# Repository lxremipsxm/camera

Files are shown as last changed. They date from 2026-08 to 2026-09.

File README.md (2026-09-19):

# Camera

## Information
1. [Component List and Hardware Notes](HardwareNotes.md)
2. [Schematic Details and Images](camCAD/README.md)

## Use (In Progress)
There are four buttons meant for a user interface

## Personal Note
This is the continuation of my stmcam project that I had been working on for a long time, in [this repository](https://github.com/lxremipsxm/stmcam) if you are interested. The goal of that project was to have a completely naked approach to building this camera, using raw C, no Hardware Abstraction Layer and minimal library usage. It was a very code-centered project, and reasonably so, as I had no electrical knowledge or knowledge of using CAD to build (or at least prototype) PCBs. At the time, I was fully confident I could make this with a perfboard and some solder at home if I had the right components, which I did eventually purchase from Digikey. However, I had selected a board without Parallel Capture/DCMI and tried to work my way around it until the workload became utterly infeasible and would have led to me making a project of subpar quality even if I succeeded. It was incredibly frustrating, but I still haven't given up on this project. This repository is a fresh start, and I am changing my approach. I have a new board planned, I have the incredible resource of KiCAD 10.0, and I have developed the skills to build my own PCBs and print them. Additionally, this time I will not dive headfirst into baremetal programming as much. I will use HAL to make a functional project, and I do eventually have to create my own interface to facilitate the use of a OV7670 library I have found on GitHub, which means I still get to code a solid amount without leaving all of it to HAL. In addition to this, because of the need for fast decision making and tight timing constraints, I will use an RTOS implementation for a multithreaded application.

So here is my camera. I am so much more confident in this project's success.

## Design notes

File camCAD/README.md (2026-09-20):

## Component Connections and Layout

### Schematics

#### STM32 Power Requirements Schematic (power_conns.kicad_sch)
This schematic is based off of the power requirements detailed in the [STM32 F405xx/F407xx datasheet](https://www.st.com/content/ccc/resource/technical/document/datasheet/ef/92/76/6d/bb/c2/4f/f7/DM00037051.pdf/files/DM00037051.pdf/jcr:content/translations/en.DM000370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) and cross-checked with the [ST Application Note AN4488](https://www.alldatasheet.com/datasheet-pdf/view/701384/STMICROELECTRONICS/AN4488.html) for good measure.

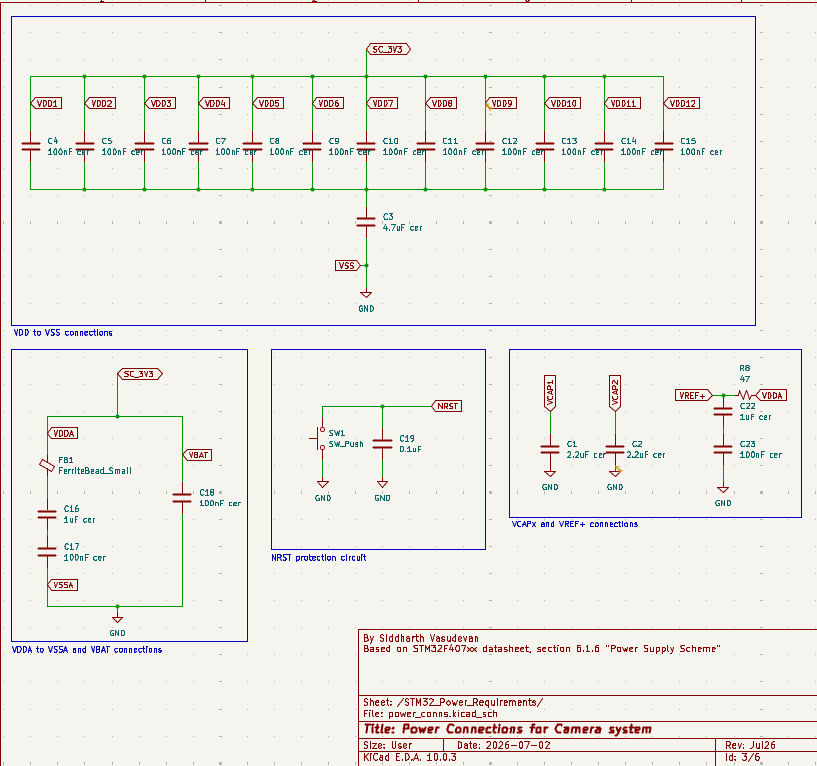
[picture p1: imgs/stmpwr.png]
Power Connections Schematic


#### Power Supply and Charging Schematic (buck.kicad_sch)
This schematic contains all of the circuitry necessary to make charging possible and exposes pins to the battery. It includes connections for a USB-C socket that serves as the charging port for the camera, connections for the Dynamic Power Path Management IC (charging + power management), the buck converter circuitry to efficiently step down the battery's 3.7V to 3.3V, and the battery terminals, which will use an XH socket. (Initially I planned to have the buck converter on a separate schematic, hence the filename, but there wasn't enough detail to justify a separate schematic)

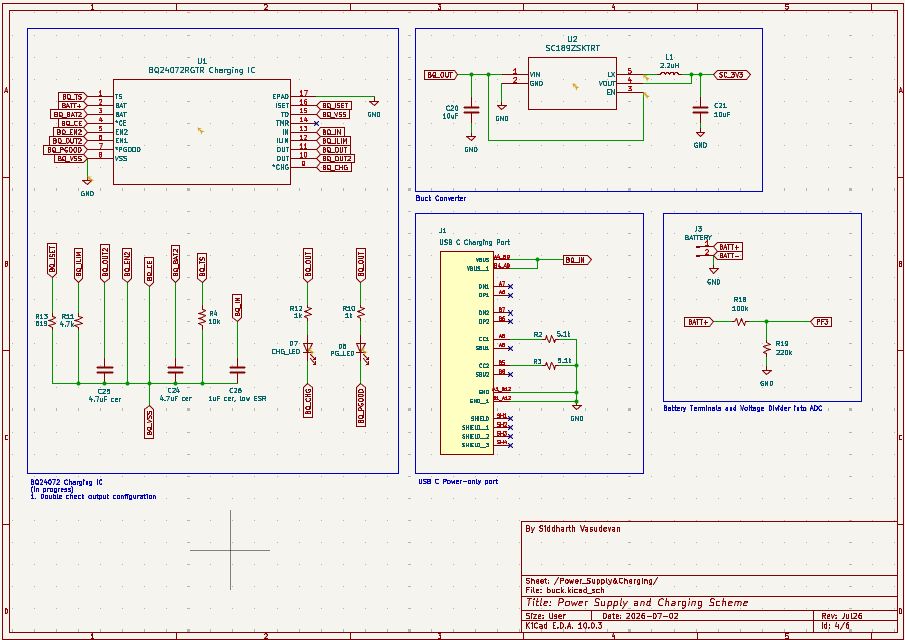
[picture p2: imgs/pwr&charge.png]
Power Supply and Charging Schematic


#### Components Schematic (components.kicad_sch)
This schematic contains the component connections that provide all the functionality of a camera. It contains the OV7670 Camera Module, the ILI9341 Display header, activity LEDs, and the MicroSD transflash breakout board.

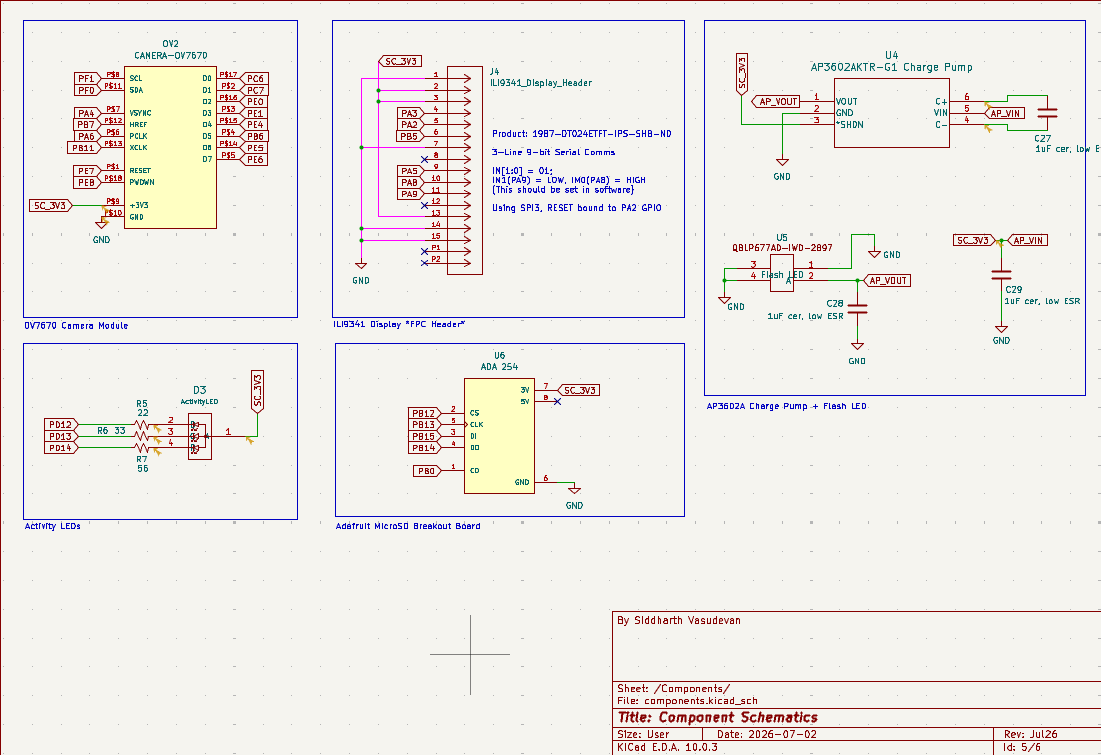
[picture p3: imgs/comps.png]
Components Schematic


#### STM32F407 schematic (f407zgt6.kicad_sch)
Contains the STM32F407ZGT6 LPQF144 chip. ~~In the near future I will put more circuits in this schematic, such as the bootloader switch.~~
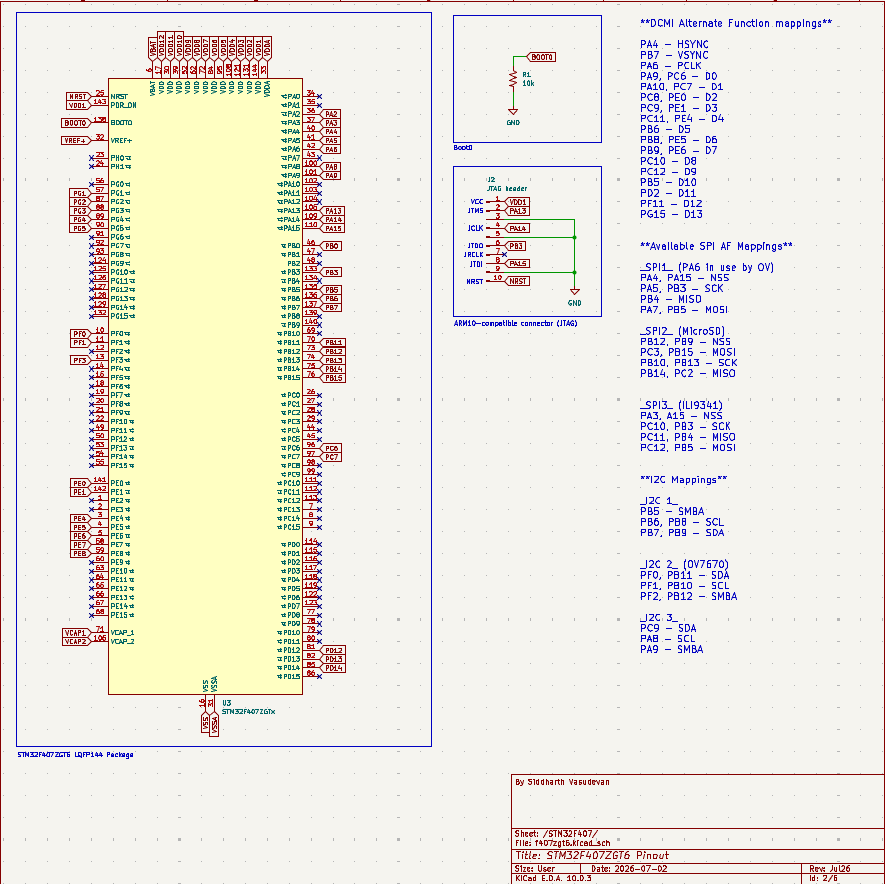
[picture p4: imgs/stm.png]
STM32 Schematic


#### User Interface (user_interface.kicad_sch)
This schematic contains the buttons that will aid the user in communicating with the camera, such as taking pictures, toggling flash, deleting pictures, and navigating saved pictures via a picture menu.

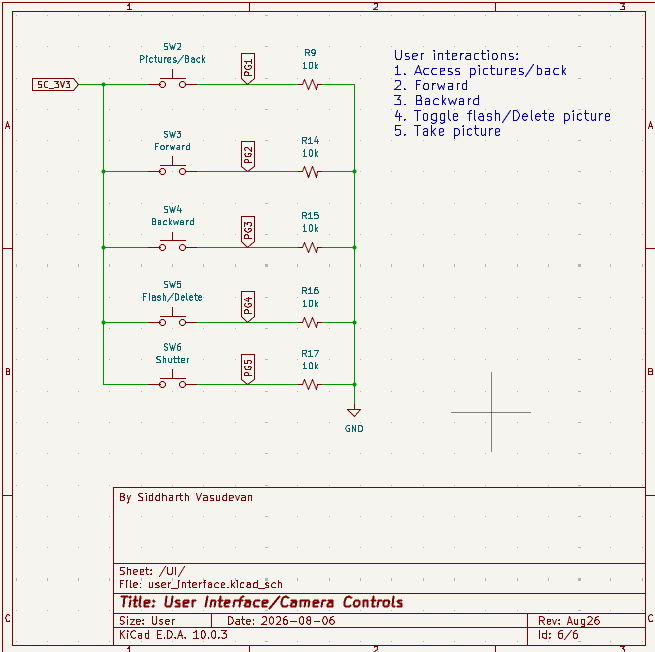
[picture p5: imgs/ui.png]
User Interface Schematic


### PCB Layout (Two Layer)
I was recommended to use four layers to separate the ground and VCC Planes better, but this is what I got routing with a two-layer PCB, with the back CU layer housing a ground fill zone. 
The following layout was verified by the DRC. All dimensions are in mm.
| Layout | 3D Model |
| --- | --- |
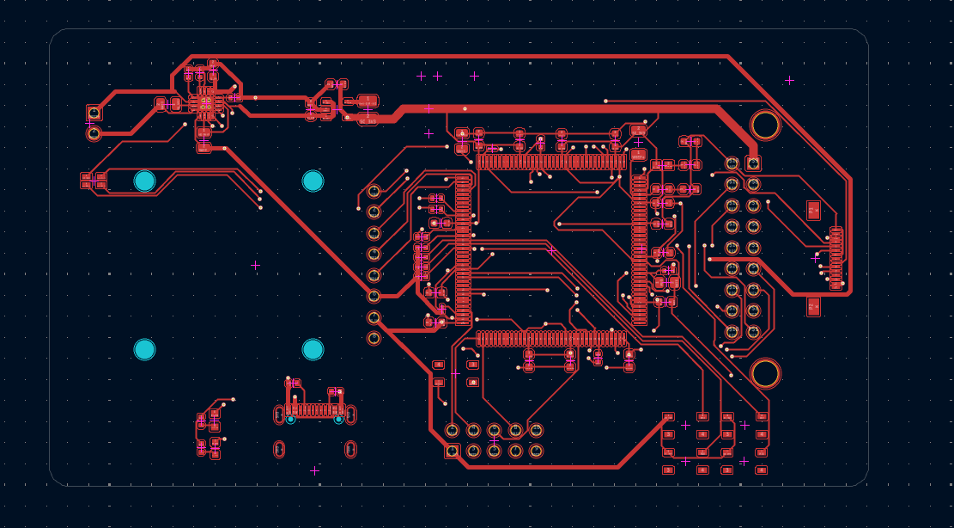
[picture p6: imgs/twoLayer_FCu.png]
Front Layout CU only
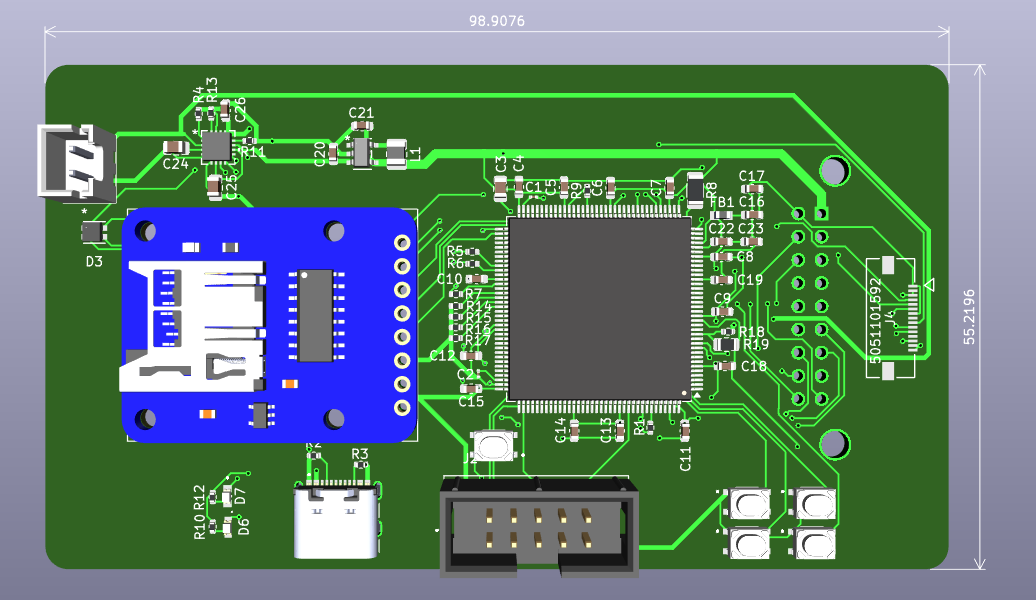
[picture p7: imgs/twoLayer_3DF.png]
Front 3D Model
|  |  |

| Back Layout | 3D Model |
| --- | --- |
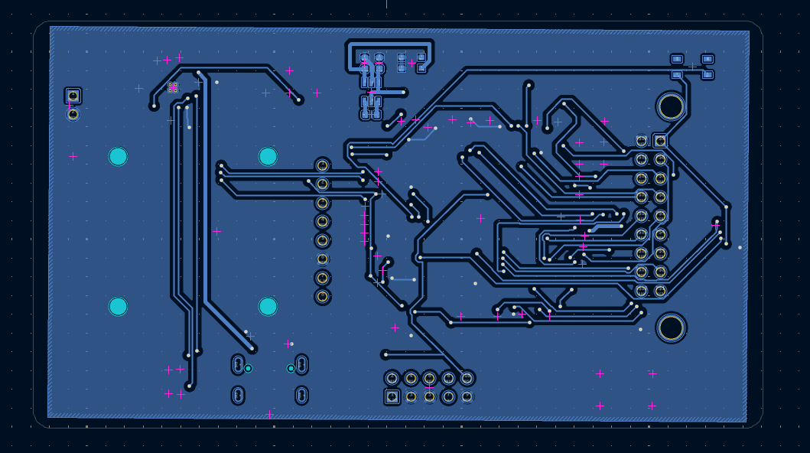
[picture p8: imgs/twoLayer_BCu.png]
Back Layout Cu
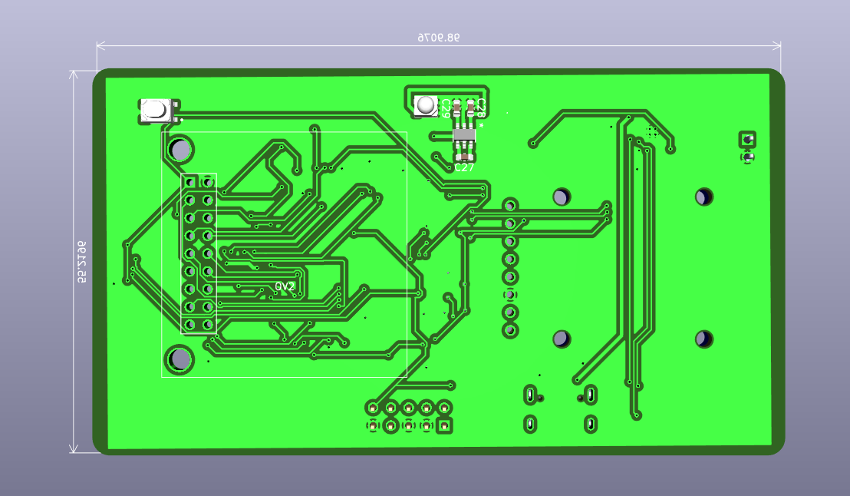
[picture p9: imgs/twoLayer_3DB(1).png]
Back 3D Model
|  |  |

### PCB Layout (Four Layer)
This PCB will be printed once I reverify the schematics and layout. I was able to make the board a little more compact with four layers.
The layout was verified by the DRC. All dimensions are in mm.

| Front CU | Back CU |
|--- | --- |
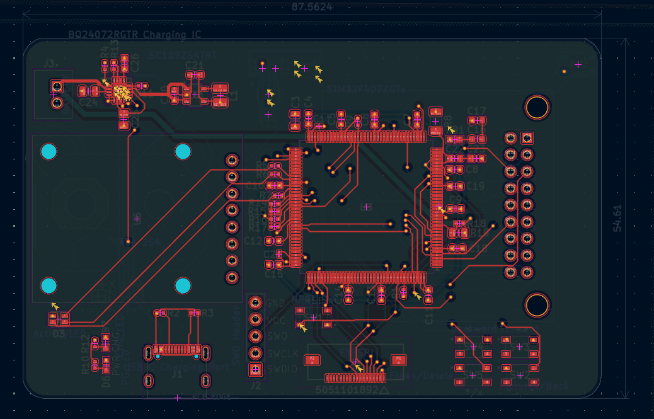
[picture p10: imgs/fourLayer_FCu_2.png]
Front Layout CU
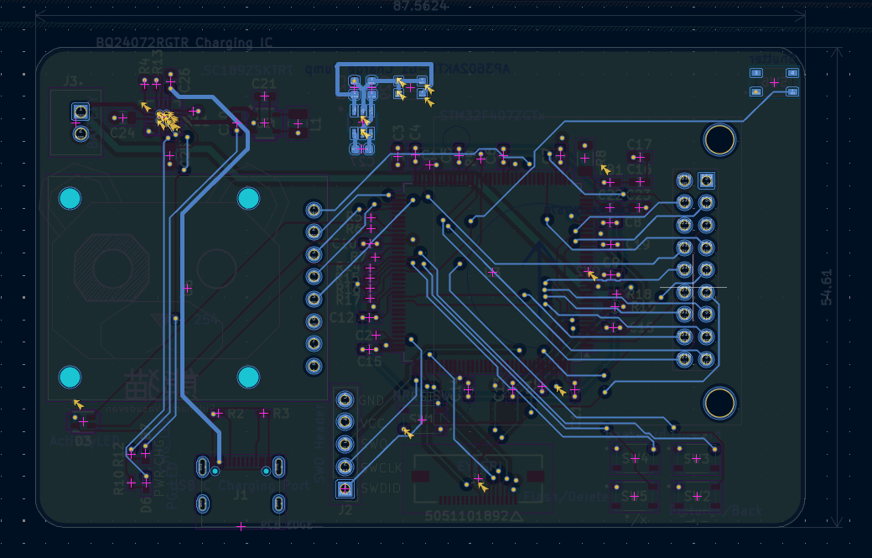
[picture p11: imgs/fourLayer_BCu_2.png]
Back Layout CU only
|  |  |
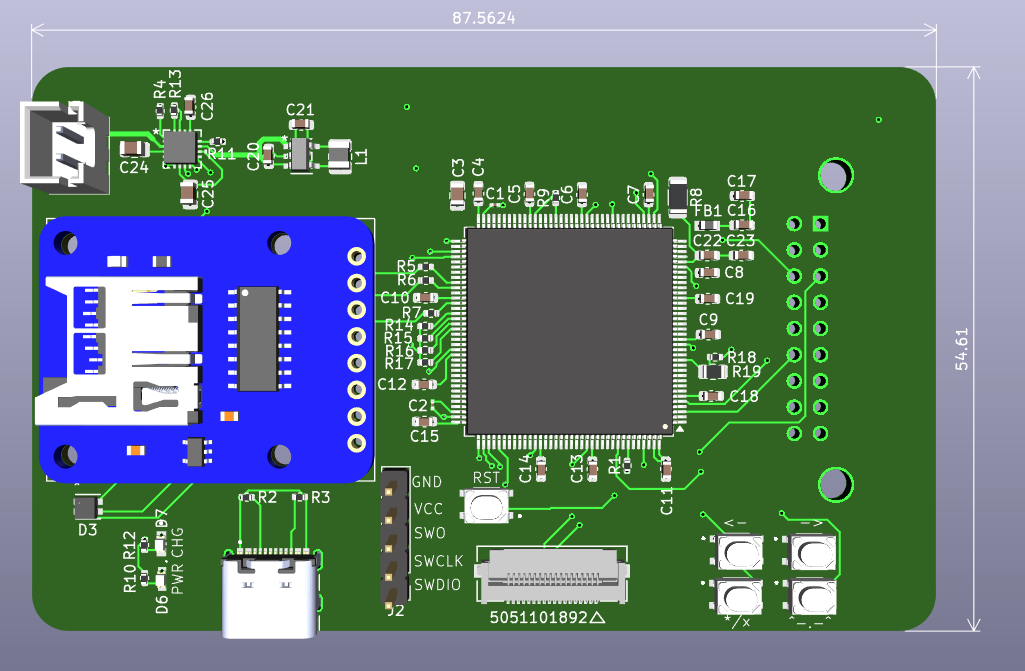
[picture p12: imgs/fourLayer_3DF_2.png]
Front 3D
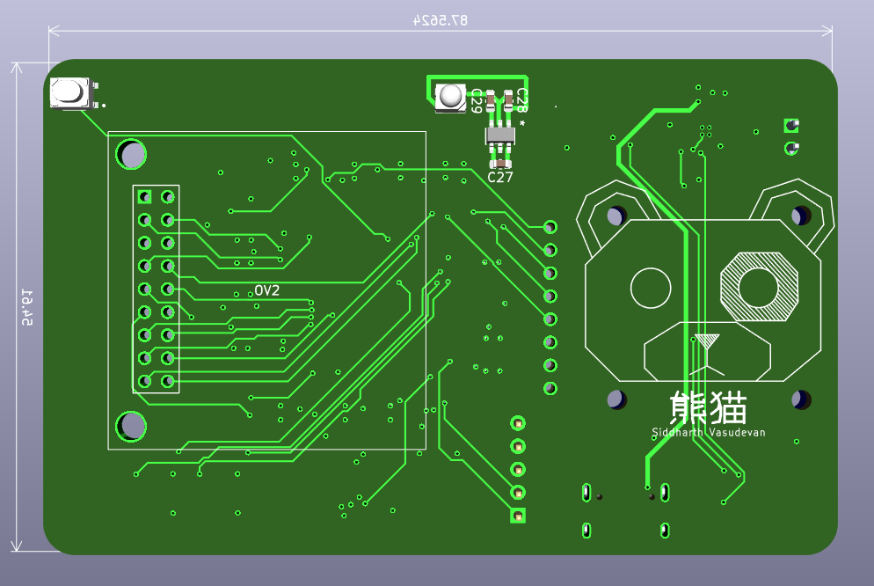
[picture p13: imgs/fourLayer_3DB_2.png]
Back 3D
|  |  |

| VCC CU | GND CU |
| --- | --- |
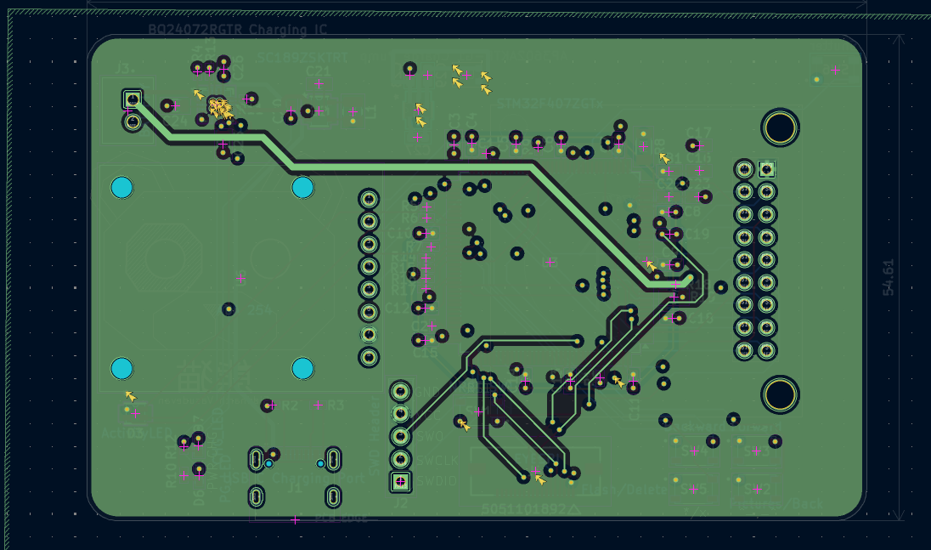
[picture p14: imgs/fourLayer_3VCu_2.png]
VCC Layout CU
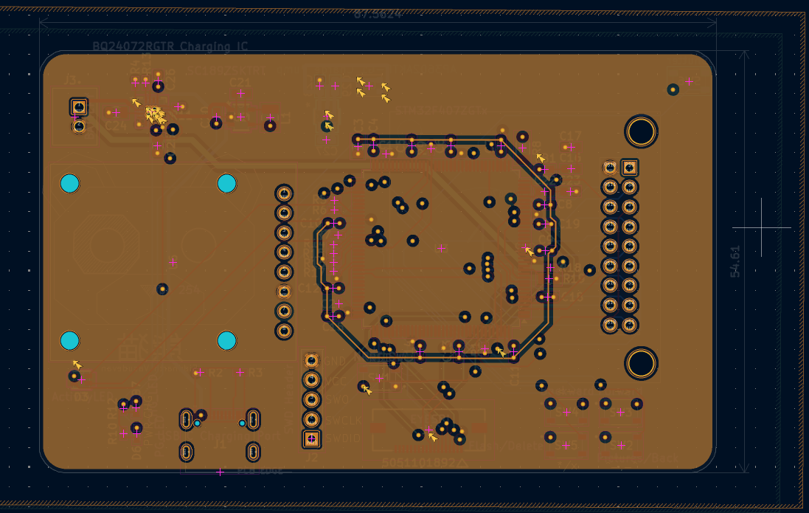
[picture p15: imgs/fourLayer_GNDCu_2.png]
GND Layout CU
|  |  |

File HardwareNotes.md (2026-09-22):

# Notes about Hardware

---

## Major Component List (Digikey Part Numbers Included)
1. STM32F407: 497-11766-ND
2. OV7670: 1188-CAMERA-OV7670-ND
3. Adafruit MicroSD Breakout: 1528-1462-ND
~~ 4. ILI9341: 1987-DT024ETFT-IPS-SHB-ND~~ 
4. Display Module (ADA 4311): 1528-4311-ND
5. RGB LED: CLMVC-FKA-CL1D1L71BB7C3C3CT-ND
6. Charge-Pump: 31-AP3602AKTR-G1CT-ND
7. Flash LED: 1516-QBLP677AD-IWD-2897CT-ND
8. Buck Converter: SC189ZSKCT-ND
9. Battery: 1471-MIKROE-4474-ND
10. Charging IC: 296-38871-1-ND
11. USB-C for Charging: 2223-UJ20-C-H-G-SMT-1-P16-TRCT-ND
12. PGOOD Indicator LED (Green): 160-LTST-C190GKTCT-ND 
13. CHG Indicator LED (Red): 160-1436-1-ND 

## Resistors, Capacitors, Inductors, and Headers
### Miscellaneous
1. SWD ARM-10 compatible header: S9169-ND
2. FPC Socket: WM12374CT-ND
3. Battery Connector: 455-B2B-XH-A-ND
4. Push Button (NRST): 4809-SKRPABE010CT-ND
5. VDDA Ferrite Bead: 490-14396-1-ND
6. Buck Converter 2.2uH Inductor (rated at least 1.5 A for system load): 587-3226-1-ND  

### Capacitors
7. 100nF (0.1uF) ceramic decoupling (STM32 power): 1276-CL10E104KC8VPNCCT-ND 
8. 1uF low ESR ceramic decoupling (charge pump): 587-6336-1-ND
9. 1uF ceramic decoupling (STM32 power): 587-6336-1-ND
10. 10uF ceramic decoupling (buck converter): 490-12538-1-ND
11. 0.1uF NRST power switch capacitor: 1276-CL10E104KC8VPNCCT-ND 
12. 4.7uF DPPM ceramic decoupling: 1276-1065-1-ND
13. STM32 VCAP 2.2uF ceramic decoupling: 478-KGM03CR50J225MHCT-ND

### Resistors
14. 619 DPPM ISET: P619LCT-ND
15. 4.7k DPPM ILIM: 311-4.7KLRCT-ND
16. 1k Indicator LED: 311-1.00KLRCT-ND 
17. 5.1k USB C Socket: P5.10KLCT-ND
18. 10k BQ_TS & BOOT0: RMCF0402FT10K0CT-ND  
19. 22 RGB_B LED: 541-22.0LCT-ND
20. 33 RGB_G LED: 541-33.0LCT-ND
21. 56 RGB_R LED: A129612CT-ND
22. 47 VDDA-VREF: P47BCCT-ND
23. 100k Voltage Divider R into ADC junction: 311-100KLRCT-ND 
24. 220k Voltage Divider R from ADC to GND: A126350CT-ND 

## STM32F407 + Recommendations from manufacturer
1. PCB should be a multilayer one with separate layers for VSS and VDD
2. Don't have one singular GND return plane, try and ground components individually
3. Recommended to put buck converter far from other components to avoid noise 
4. Unused counters or I/O should not be left free, either set to 1/0 or peripheral disabled.
5. Draws <= 150mA

## OV7670
1. Draws ~18 mA, maximum not provided by documentation, USE 25-50mA just in case

## MicroSD
1. Draws ~100mA worst case scenario

## SWD Header ~~JTAG header~~
1. Exposes the JTAG peripheral that can be used to debug with an STLink

## ILI9341

### Header
1. 

### Actual device
1. Backlight draws <= 60mA
2. Functional part draws <= 15mA

## AP3602A Regulated Charge-Pump
1. Outputs up to 250mA current after charging
2. SHDN cannot be floating, tie to GPIO pin HIGH (enable) or LOW, never leave floating
3. Bypass VOUT with a 1uF to 22uF low ESR *ceramic* cap to GND
4. Bypass VIN with another 1uf-22uF low ESR ceramic cap to GND
5. Flying capacitor is separate from these two capacitors
6. Draws ~75mA while firing flash

## Flash LED
1. Current draw see Charge Pump^
2. V_LED = 3.2V
3. V_Out (Charge-Pump) = 5V
4. Required LED Current ~= 50mA
5. R (resistor) >= V/I <= (5-3.2V)/(50*10^-3) >= 36 Ohms

## SC189Z 3.6V->3.3V Buck Converter
1. EN pin should be tied to VIN on itself
2. LX is a switching node, connect inductor between here and output cap
3. Place components as closely as possible to the SC189Z.
4. For SOT-23 package at Vin = 4.0V, Vout = 3.3V and I_load ~= 560 mA, efficiency is roughly 93%

## Power + Activity RGBLED
1. Common Anode (3.3V)
2. PWM-controlled, using Advanced timer TIM4
3. B CH1, G CH2, R CH3
4. Draws ~(25 + 13 + 13) mA = ~51 mA

### Resistor and control details
V_GPIO <= 3.3V

#### Red
V_red = 1.9 V
I_avg = 25*10^-3 A

R_red >= (3.3-1.9)/(2.5*10^-3) = 53.85 Ohm ~= 56 Ohm

#### Green
V_green = 2.9 V
I_avg = 13*10^-3 A

R_green = (3.3-2.9)/(13*10^-3) >= 30.77 Ohm ~= 33 Ohm

#### Blue
V_blue = 3.0 V
I_avg = 13*10^-3 A

R_blue = (3.3-3.0)/(13*10^-3) >= 23.08 Ohm ~= 22 Ohm

# Power Considerations for Battery

## Current Needs of Components
1. STM32 = 150mA
2. OV7670 = 50 mA
3. MicroSD Breakout = 100mA
4. ILI9341 = 75mA
5. Charge-pump + Flash = 75mA
6. LEDs ~= 51 + 3(20) = 111mA

Total = 150 + 50 + 100 + 75 + 75 + 111 = 350 + 75 + 111 = 561 mA

## Safety Margin and Buck Converter Efficiency
~~Once I choose a buck converter, I will include the efficiency of that to decide the battery configuration.~~
With the selected buck converter, the SC189Z, and a 4.0V input with 3.3V output configuration, the efficiency is ~93%.

Using this and a safety margin of 20% to account for battery aging:
Estimated needs (safety margin of 20%, 4 hour usage) = (561 * 4)/0.93 * 1.2 = 2895.5 mAh, which we can round up to 3000mAh.

Battery selected (Items 10 and 11 in **Component List**).

# Charging method

## MLP805660 Battery pack
1. 3.7V, 3000mAh
2. Discharges 0.2 C-rate
3. Standard charging 0.5C (C-rate, NOT coulombs like I initially thought), takes about 5.5-6.5 hours to charge fully 
4. Current needed for standard charging, therefore, is 0.5C * 3000mAh = 1.5A

## BQ24072 Charging IC
1. ILIM doesn't need to be programmed in EN2=LO EN1=HI mode (USB 500mA), so I've selected a 4.7k Ohm resistor to GND
2. $797 <= $K_{ISET}$ <= 975$. I use this to calculate the resistor needed to program the ISET pin.
3. $I_{CHG}$ can be 1.5A, which I will keep. $R_{ISET} = K_{ISET}/I_{CHG}$
4. $531.3 \le R_{ISET} \le 650$. The valid range is $590 \ge r \ge 8.9k$. I will use $R_{ISET} = 619$  

## USB C Socket
1. 

# Schematic/Layout Verification and Code Information

## ADA 4311 Display
(Verified 9/20)
| Header Pin # | 4311 Pin Name | STM Pin # | STM GPIO AF |
| ----- | ----- | ----- | ----- |
| 4 | SCK | PC10 | SPI3_SCK |
| 5 | MOSI | PC12 | SPI3_MOSI |
| 6 | MISO | PC11 | SPI3_MISO |
| 7 | DC (Data/CMD) | PC13 | NA |
| 8 | RESET | PC14 | NA |
| 9 | TFTCS | PA15 | SPI3_NSS |

## OV7670 Camera Module 
(Verified 9/20)

| OV Pin Name | STM Pin # | STM GPIO AF |
| --- | --- | --- |
| SCL | PF1 | I2C2_SCL | 
| SDA | PF0 | I2C2_SDA |
| VSYNC | PB7 | DCMI_VSYNC |
| HREF | PA4 | DCMI_HSYNC |
| PCLK | PA6 | DCMI_PIXCLK |
| XCLK | PB11 | TIM2_CH4 |
| RESET | PE7 | NA | 
| PWDWN | PE8 | NA |
| D0 | PC6 | DCMI_D0 |
| D1 | PC7 | DCMI_D1 |
| D2 | PE0 | DCMI_D2 |
| D3 | PE1 | DCMI_D3 |
| D4 | PE4 | DCMI_D4 |
| D5 | PB6 | DCMI_D5 |
| D6 | PE5 | DCMI_D6 |
| D7 | PE6 | DCMI_D7 |

## ADA 254 MicroSD Breakout
(Verified 9/20)

| 254 Pin Name | STM Pin # | STM GPIO AF |
| --- | --- | --- |
| CS | PB12 | SPI2_NSS |
| CLK | PB13 | SPI2_SCK |
| DI | PB15 | SPI2_MOSI |
| DO | PB14 | SPI2_MISO |
| CD (card detect) | PB0 | NA |

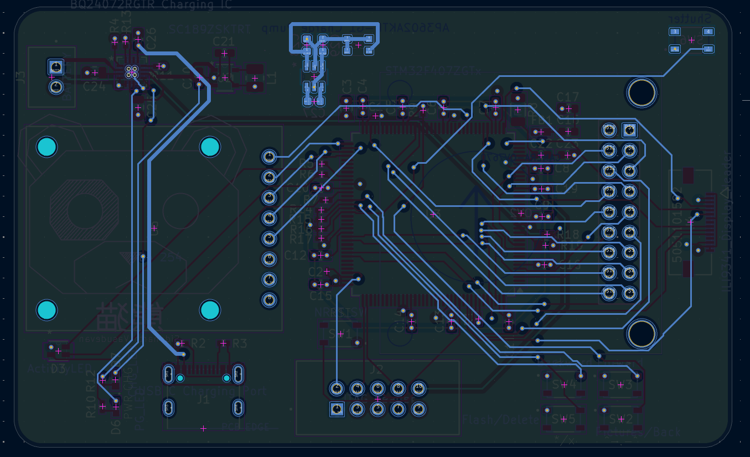
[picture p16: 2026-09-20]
imgs/fourLayer_BCu_1.png

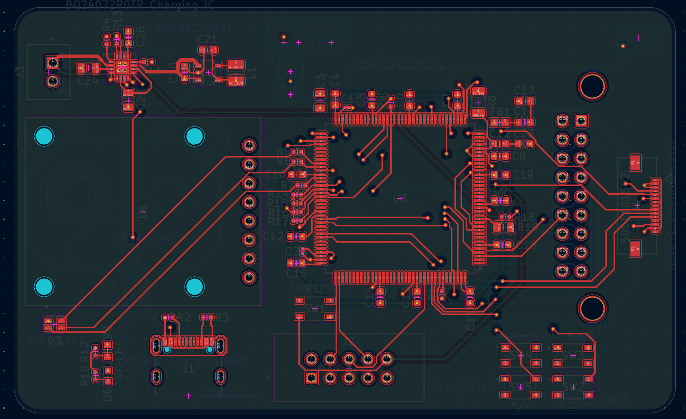
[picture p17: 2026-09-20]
imgs/fourLayer_FCu_1.png

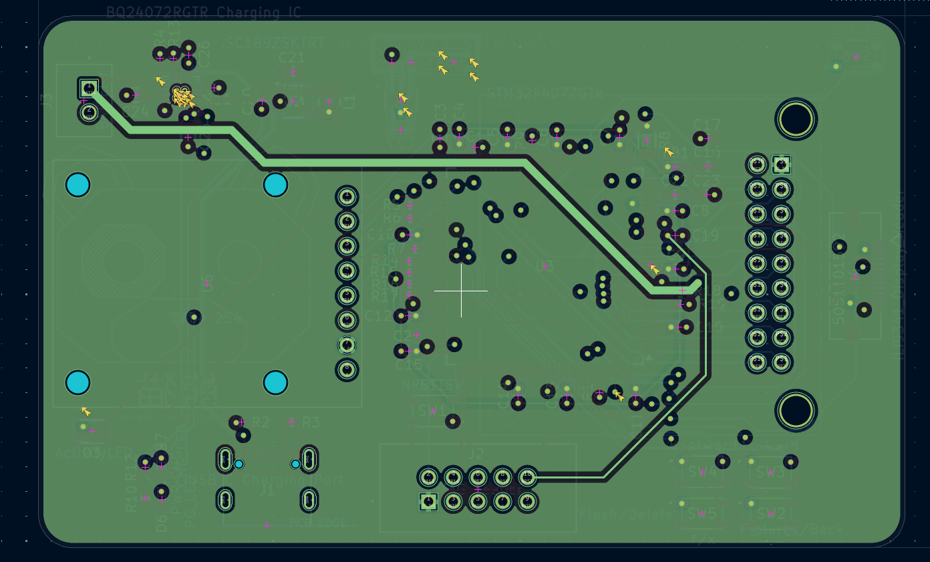
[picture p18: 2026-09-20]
imgs/fourLayer_3VCu_1.png

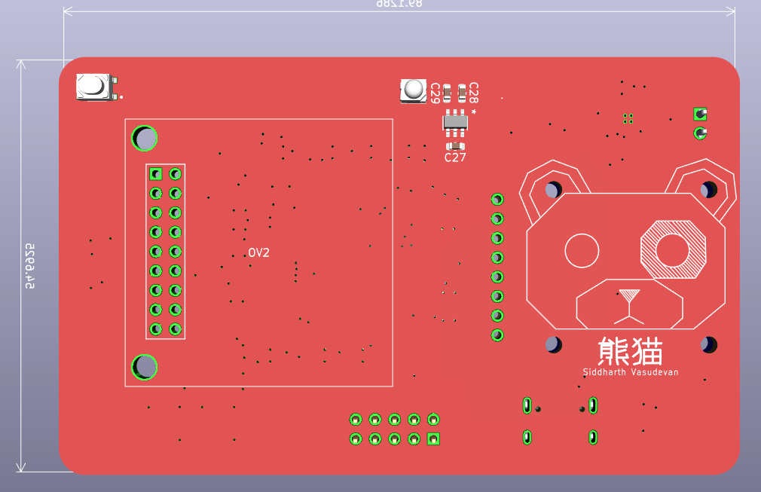
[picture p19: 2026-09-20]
imgs/fourLayer_3DB_1.png

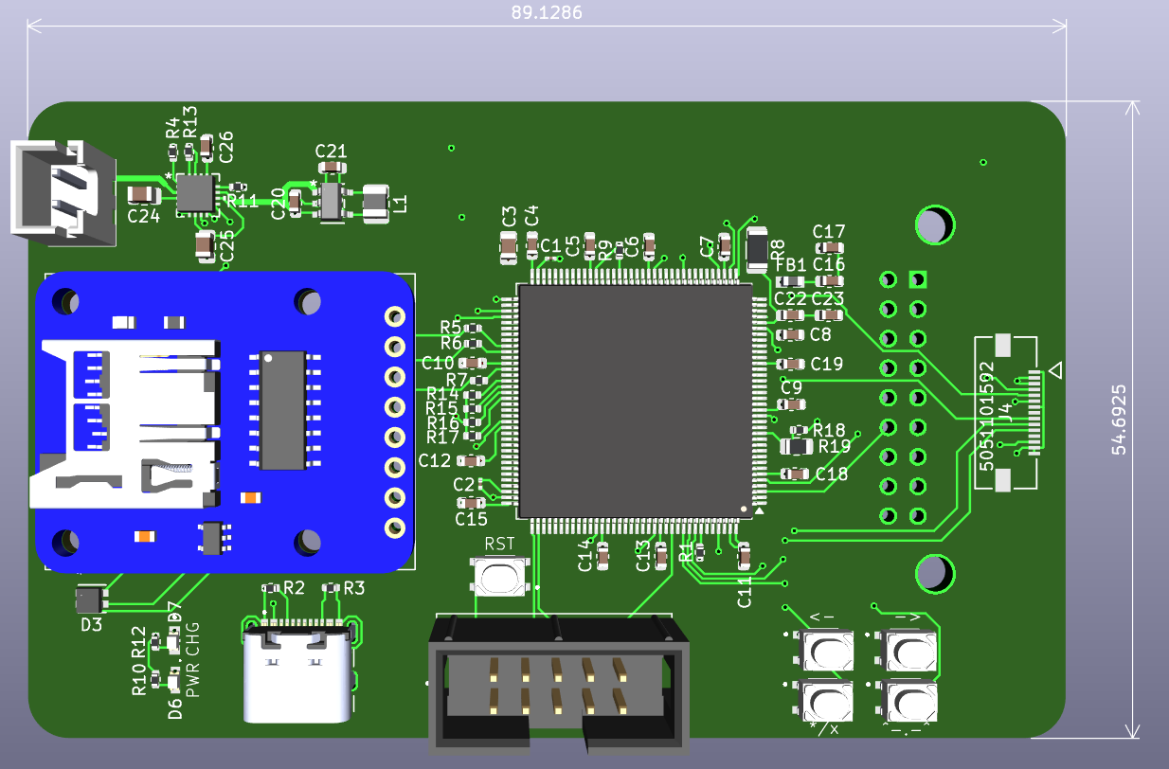
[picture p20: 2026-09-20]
imgs/fourLayer_3DF_1.png

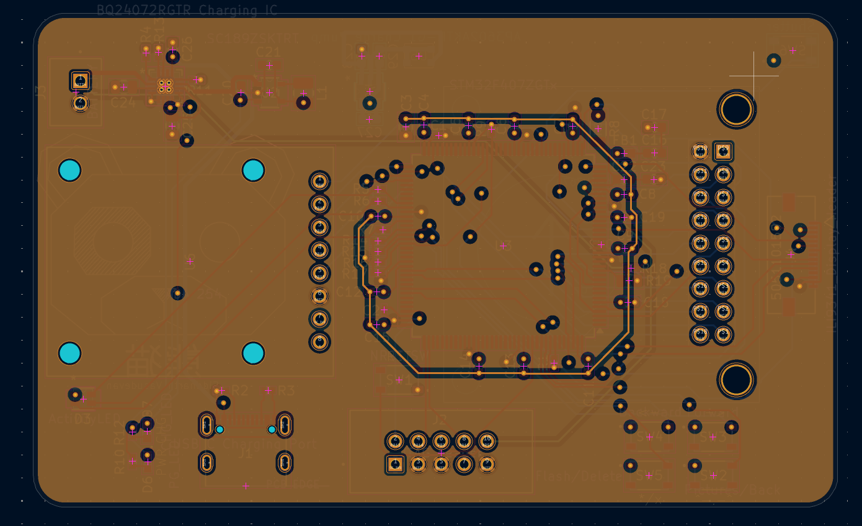
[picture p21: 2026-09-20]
imgs/fourLayer_GNDCu_1.png

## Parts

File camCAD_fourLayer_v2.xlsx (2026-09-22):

Reference | Value | Digikey Part No | Qty | Buy Qty | Total Price | Footprint | Datasheet
R8 | 47 | P47BCCT-ND | 1 | 4 | ! | Resistor_SMD:R_1206_3216Metric
R19 | 220k | A126350CT-ND | 1 | 10 | $0.42 | Resistor_SMD:R_0805_2012Metric
R18 | 100k | 311-100KLRCT-ND | 1 | 10 | $0.42 | Resistor_SMD:R_0402_1005Metric
R13 | 619 | P619LCT-ND | 1 | 10 | $0.31 | Resistor_SMD:R_0402_1005Metric
R11 | 4.7k | 311-4.7KJRCT-ND | 1 | 10 | $0.20 | Resistor_SMD:R_0402_1005Metric
R10,R12 | 1k | 311-1.00KLRCT-ND | 2 | 10 | $0.21 | Resistor_SMD:R_0402_1005Metric
R7 | 56 | A129612CT-ND | 1 | 10 | $0.30 | Resistor_SMD:R_0402_1005Metric
R6 | 33 | 541-33.0LCT-ND | 1 | 10 | $0.32 | Resistor_SMD:R_0402_1005Metric
R5 | 22 | 541-22.0LCT-ND | 1 | 4 |  | Resistor_SMD:R_0402_1005Metric
R2,R3 | 5.1k | P5.10KLCT-ND | 2 | 5 |  | Resistor_SMD:R_0402_1005Metric
R1,R4,R9,R14,R15,R16,R17 | 10k | RMCF0402FT10K0CT-ND | 7 | 10 |  | Resistor_SMD:R_0402_1005Metric
U3 | STM32F407ZGTx | 497-11766-ND | 1 | 1 |  | Package_QFP:LQFP-144_20x20mm_P0.5mm | https://www.st.com/resource/en/datasheet/stm32f407zg.pdf
L1 | 2.2uH | 587-3226-1-ND | 1 | 4 |  | Inductor_SMD:L_1008_2520Metric
J2 | SWD Header |  | 1 | 0 |  | Connector_PinHeader_2.54mm:PinHeader_1x05_P2.54mm_Vertical
J4 | EYESPI | WM12374CT-ND | 1 | 3 |  | CON_5051101892_MOL | https://www.molex.com/en-us/products/part-detail-pdf/5051101892?display=pdf
C3,C24,C25 | 4.7uF cer | 1276-1065-1-ND | 3 | 3 |  | Capacitor_SMD:C_0805_2012Metric
C26,C27,C28,C29 | 1uF cer, low ESR | 587-6336-1-ND | 4 | 0 |  | Capacitor_SMD:C_0603_1608Metric
C20,C21 | 10uF |  | 2 | 0 |  | Capacitor_SMD:C_0603_1608Metric
C19 | 0.1uF |  | 1 | 0 |  | Capacitor_SMD:C_0603_1608Metric
C16,C22 | 1uF cer |  | 2 | 0 |  | Capacitor_SMD:C_0603_1608Metric
C4,C5,C6,C7,C8,C9,C10,C11,C12,C13,C14,C15,C17,C18,C23 | 100nF cer |  | 15 | 0 |  | Capacitor_SMD:C_0603_1608Metric
C1,C2 | 2.2uF cer | 478-KGM03CR50J225MHCT-ND | 2 | 5 |  | Capacitor_SMD:C_0201_0603Metric
SW6 | Shutter | 4809-SKRPABE010CT-ND | 1 | 1 |  | 1_Switches:SW_SKRPABE010
SW5 | Flash/Delete | 4809-SKRPABE010CT-ND | 1 | 1 |  | 1_Switches:SW_SKRPABE010
SW4 | Backward | 4809-SKRPABE010CT-ND | 1 | 1 |  | 1_Switches:SW_SKRPABE010
SW3 | Forward | 4809-SKRPABE010CT-ND | 1 | 1 |  | 1_Switches:SW_SKRPABE010
SW2 | Pictures/Back | 4809-SKRPABE010CT-ND | 1 | 1 |  | 1_Switches:SW_SKRPABE010
SW1 | NRST_SW | 4809-SKRPABE010CT-ND | 1 | 3 |  | 1_Switches:SW_SKRPABE010
J1 | USB C Charging Port | 2223-UJ20-C-H-G-SMT-1-P16-TRCT-ND | 1 | 2 |  | 1_Sockets:SAMESKY_UJ20-C-H-G-SMT-1-P16-TR
U6 | ADA 254 | 1528-1462-ND | 1 | 2 |  | 1_MicroSD:MODULE_254
U5 | Flash LED | 1516-QBLP677AD-IWD-2897CT-ND | 1 | 2 |  | 1_LEDs:QBLP677AD-IWD-2897
D6 | PG_LED | 160-LTST-C190GKTCT-ND | 1 | 2 |  | 1_LEDs:LEDM1608X80_G
D7 | CHG_LED | 160-1436-1-ND | 1 | 2 |  | 1_LEDs:LEDC1608X35N_R
D3 | ActivityLED | CLMVC-FKA-CL1D1L71BB7C3C3CT-ND | 1 | 2 |  | 1_LEDs:CLMVC-FKA-CL1D1L71BB7C3C3_CRE | CLMVC-FKA-CL1D1L71BB7C3C3
J3 | BATTERY | 455-B2B-XH-A-ND | 1 | 2 |  | 1_Headers:JST_B2B-XH-A
FB1 | FerriteBead_Small | 490-14396-1-ND | 1 | 3 |  | 1_FerriteBeads:BEADC1608X95N
U1 | BQ24072RGTR Charging IC | 296-38871-1-ND | 1 | 2 |  | 1_DPPMs:RGT16_1P7X1P7 | https://www.ti.com/lit/gpn/bq24072
U4 | AP3602AKTR-G1 Charge Pump | 31-AP3602AKTR-G1CT-ND | 1 | 2 |  | 1_ChargePump:SOT-23-6_DIO | AP3602AKTR-G1
OV2 | CAMERA-OV7670 |  | 1 | 0 |  | 1_Cameras:CAMERA-OV7670-DIP
U2 | SC189ZSKTRT | SC189ZSKCT-ND | 1 | 2 |  | 1_BuckConverters:SOT23-5-SC189_SEM | SC189ZSKTRT
 | ADA4311 | 1528-4311-ND | 1 | 1
 | Battery | 1471-MIKROE-4474-ND | 1 | 1
 |  |  |  |  | $2.18

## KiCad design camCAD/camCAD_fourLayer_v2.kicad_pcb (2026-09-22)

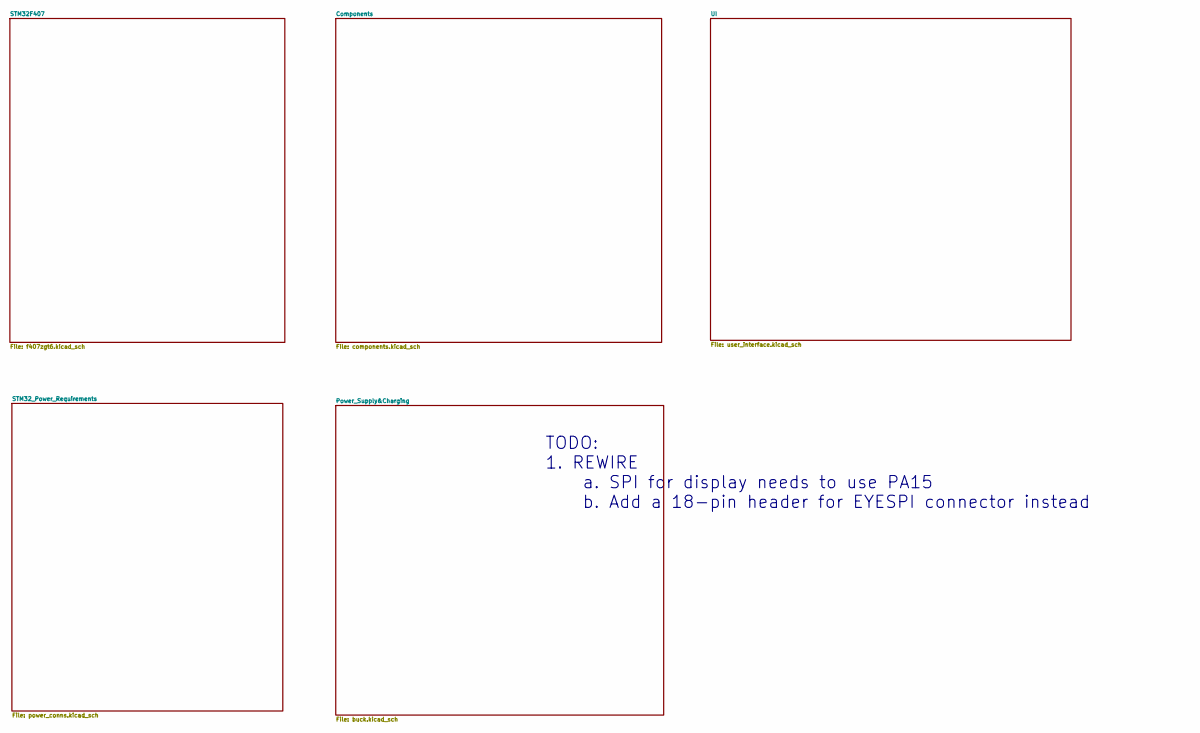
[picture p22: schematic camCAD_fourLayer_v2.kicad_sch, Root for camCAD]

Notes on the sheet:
TODO: 1. REWIRE a. SPI for display needs to use PA15 b. Add a 18-pin header for EYESPI connector instead

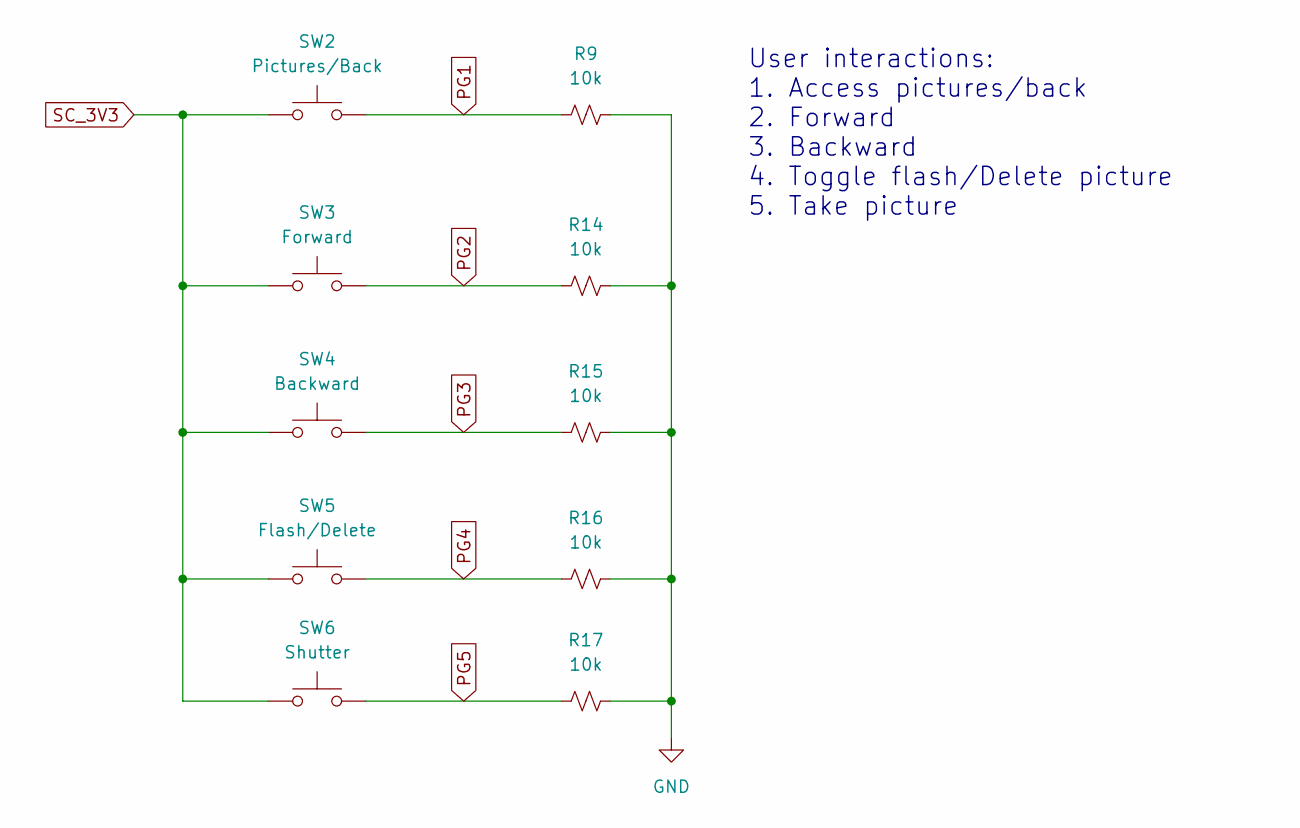
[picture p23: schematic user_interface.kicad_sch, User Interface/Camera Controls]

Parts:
R9, R14, R15, R16, R17: 10k; R_0402_1005Metric
SW2: Pictures/Back; SW_SKRPABE010
SW3: Forward; SW_SKRPABE010
SW4: Backward; SW_SKRPABE010
SW5: Flash/Delete; SW_SKRPABE010
SW6: Shutter; SW_SKRPABE010

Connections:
BATT-: R9.2, R14.2, R15.2, R16.2, R17.2; also elsewhere on the board
PG1: R9.1, SW2.2; also elsewhere on the board
PG2: R14.1, SW3.2; also elsewhere on the board
PG3: R15.1, SW4.2; also elsewhere on the board
PG4: R16.1, SW5.2; also elsewhere on the board
PG5: R17.1, SW6.2; also elsewhere on the board
SC_3V3: SW2.1, SW3.1, SW4.1, SW5.1, SW6.1; also elsewhere on the board

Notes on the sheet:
User interactions: 1. Access pictures/back 2. Forward 3. Backward 4. Toggle flash/Delete picture 5. Take picture

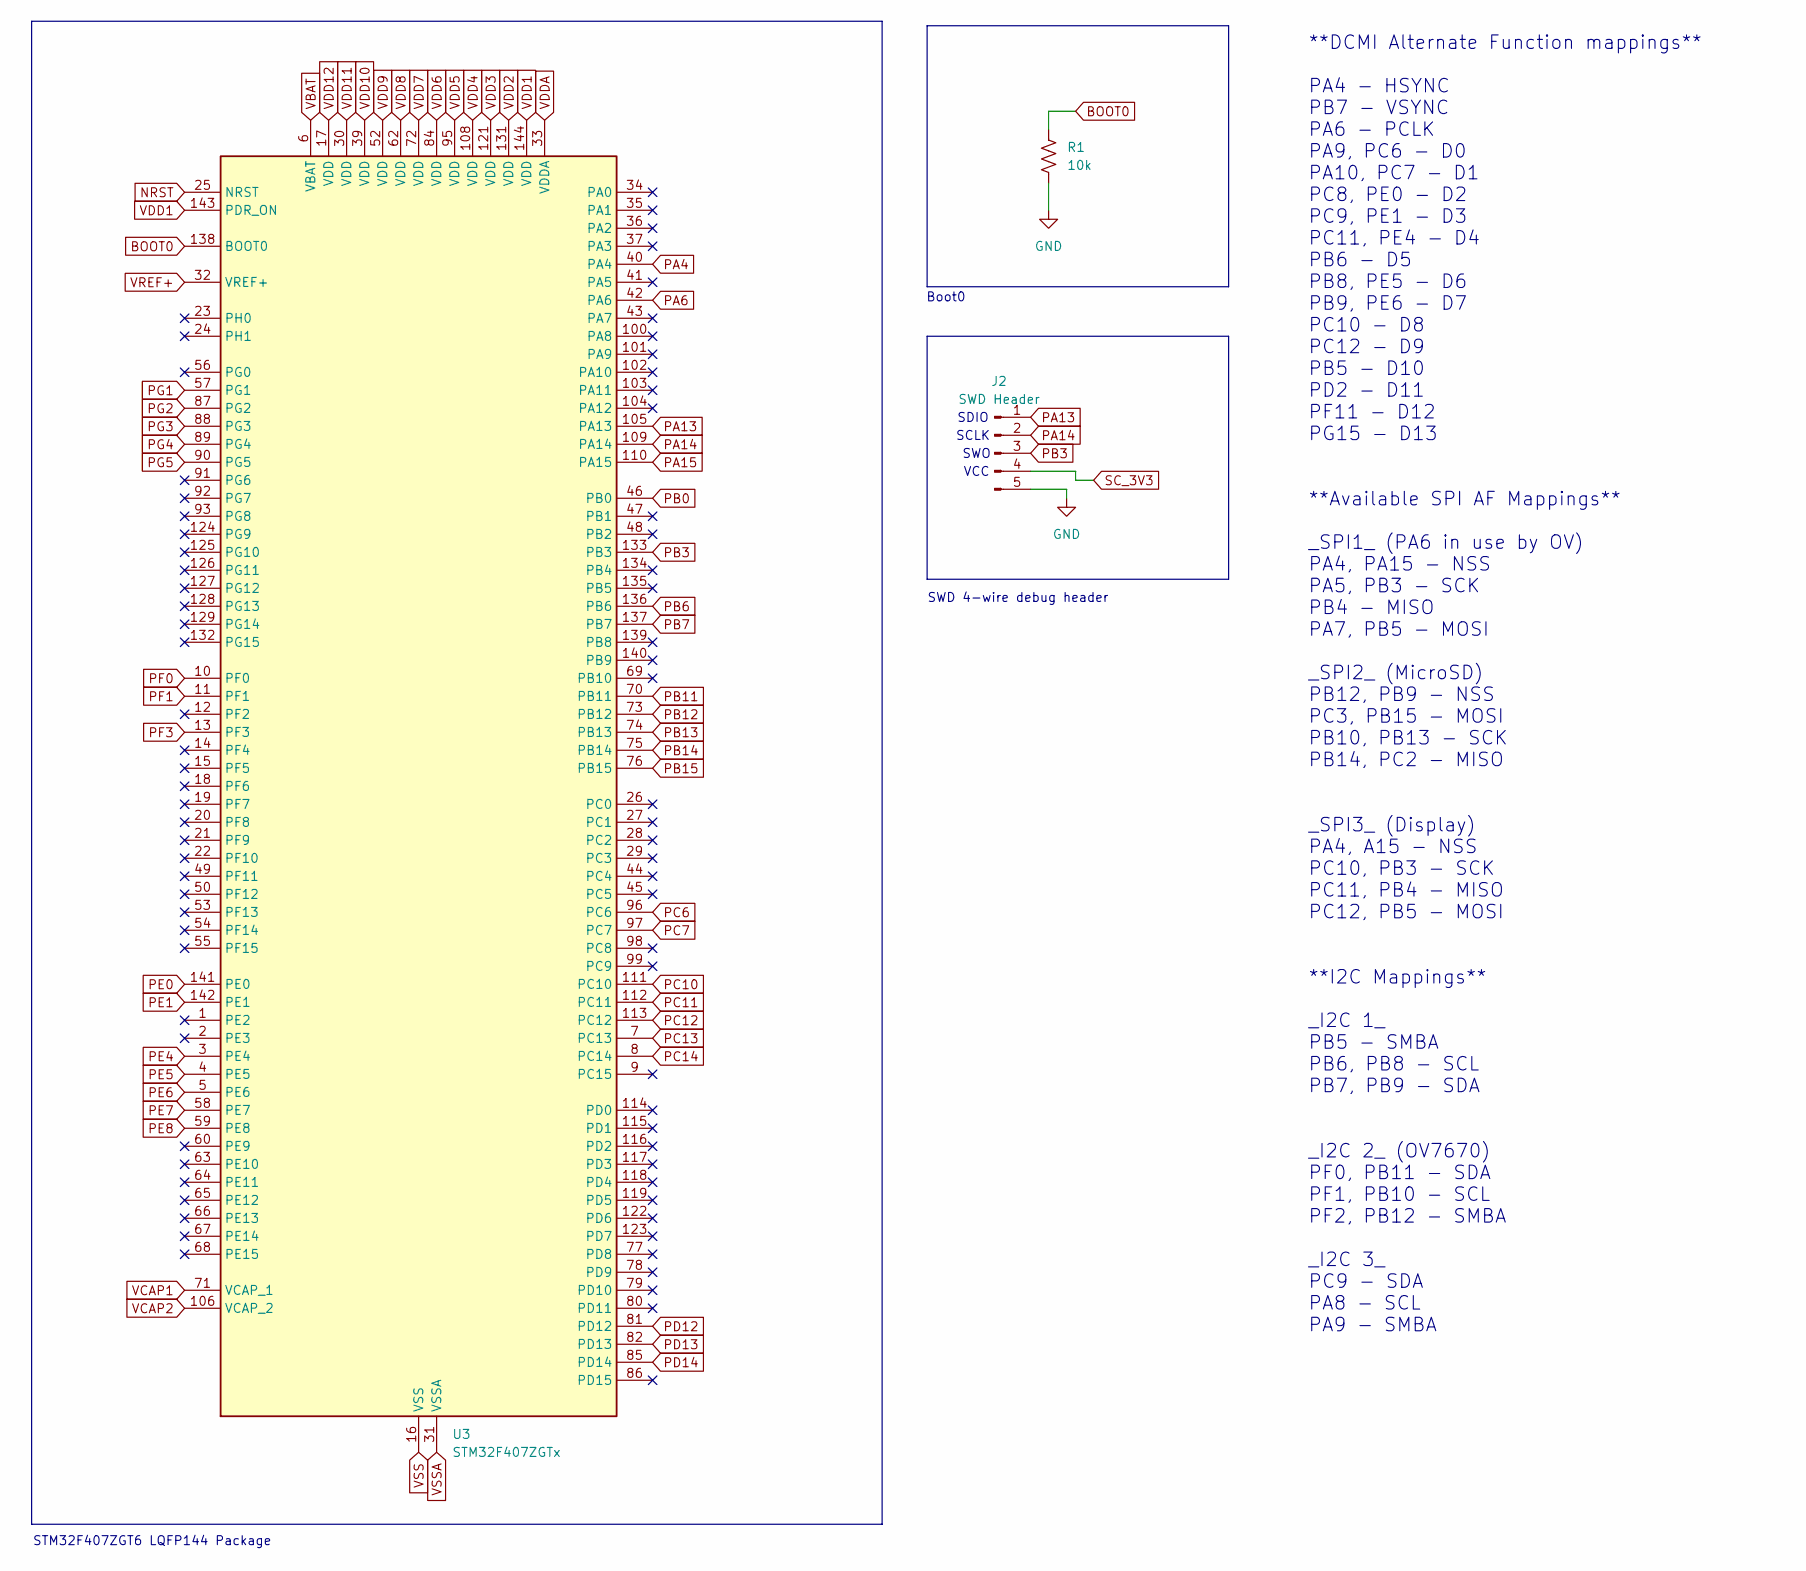
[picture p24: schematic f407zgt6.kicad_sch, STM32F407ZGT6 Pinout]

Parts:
J2: SWD Header; PinHeader_1x05_P2.54mm_Vertical
R1: 10k; R_0402_1005Metric
U3: STM32F407ZGTx; LQFP-144_20x20mm_P0.5mm

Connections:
BATT-: J2.5, R1.2, U3.16 (VSS), U3.31 (VSSA), U3.38 (VSS), U3.51 (VSS), U3.61 (VSS), U3.83 (VSS), U3.94 (VSS), U3.107 (VSS), U3.120 (VSS), U3.130 (VSS); also elsewhere on the board
BOOT0: R1.1, U3.138 (BOOT0)
NRST: U3.25 (NRST); also elsewhere on the board
PA4: U3.40 (PA4); also elsewhere on the board
PA6: U3.42 (PA6); also elsewhere on the board
PA13: J2.1, U3.105 (PA13)
PA14: J2.2, U3.109 (PA14)
PA15: U3.110 (PA15); also elsewhere on the board
PB0: U3.46 (PB0); also elsewhere on the board
PB3: J2.3, U3.133 (PB3)
PB6: U3.136 (PB6); also elsewhere on the board
PB7: U3.137 (PB7); also elsewhere on the board
PB11: U3.70 (PB11); also elsewhere on the board
PB12: U3.73 (PB12); also elsewhere on the board
PB13: U3.74 (PB13); also elsewhere on the board
PB14: U3.75 (PB14); also elsewhere on the board
PB15: U3.76 (PB15); also elsewhere on the board
PC6: U3.96 (PC6); also elsewhere on the board
PC7: U3.97 (PC7); also elsewhere on the board
PC10: U3.111 (PC10); also elsewhere on the board
PC11: U3.112 (PC11); also elsewhere on the board
PC12: U3.113 (PC12); also elsewhere on the board
PC13: U3.7 (PC13); also elsewhere on the board
PC14: U3.8 (PC14); also elsewhere on the board
PD12: U3.81 (PD12); also elsewhere on the board
PD13: U3.82 (PD13); also elsewhere on the board
PD14: U3.85 (PD14); also elsewhere on the board
PE0: U3.141 (PE0); also elsewhere on the board
PE1: U3.142 (PE1); also elsewhere on the board
PE4: U3.3 (PE4); also elsewhere on the board
PE5: U3.4 (PE5); also elsewhere on the board
PE6: U3.5 (PE6); also elsewhere on the board
PE7: U3.58 (PE7); also elsewhere on the board
PE8: U3.59 (PE8); also elsewhere on the board
PF0: U3.10 (PF0); also elsewhere on the board
PF1: U3.11 (PF1); also elsewhere on the board
PF3: U3.13 (PF3); also elsewhere on the board
PG1: U3.57 (PG1); also elsewhere on the board
PG2: U3.87 (PG2); also elsewhere on the board
PG3: U3.88 (PG3); also elsewhere on the board
PG4: U3.89 (PG4); also elsewhere on the board
PG5: U3.90 (PG5); also elsewhere on the board
SC_3V3: J2.4, U3.6 (VBAT), U3.17 (VDD), U3.30 (VDD), U3.33 (VDDA), U3.39 (VDD), U3.52 (VDD), U3.62 (VDD), U3.72 (VDD), U3.84 (VDD), U3.95 (VDD), U3.108 (VDD), U3.121 (VDD), U3.131 (VDD), U3.143 (PDR_ON), U3.144 (VDD); also elsewhere on the board
VCAP1: U3.71 (VCAP_1); also elsewhere on the board
VCAP2: U3.106 (VCAP_2); also elsewhere on the board
VREF+: U3.32 (VREF+); also elsewhere on the board

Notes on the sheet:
SCLK
Boot0
**DCMI Alternate Function mappings** PA4 - HSYNC PB7 - VSYNC PA6 - PCLK PA9, PC6 - D0 PA10, PC7 - D1 PC8, PE0 - D2 PC9, PE1 - D3 PC11, PE4 - D4 PB6 - D5 PB8, PE5 - D6 PB9, PE6 - D7 PC10 - D8 PC12 - D9 PB5 - D10 PD2 - D11 PF11 - D12 PG15 - D13 **Available SPI AF Mappings** _SPI1_ (PA6 in use by OV) 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
STM32F407ZGT6 LQFP144 Package
VCC
SWD 4-wire debug header
SDIO
SWO

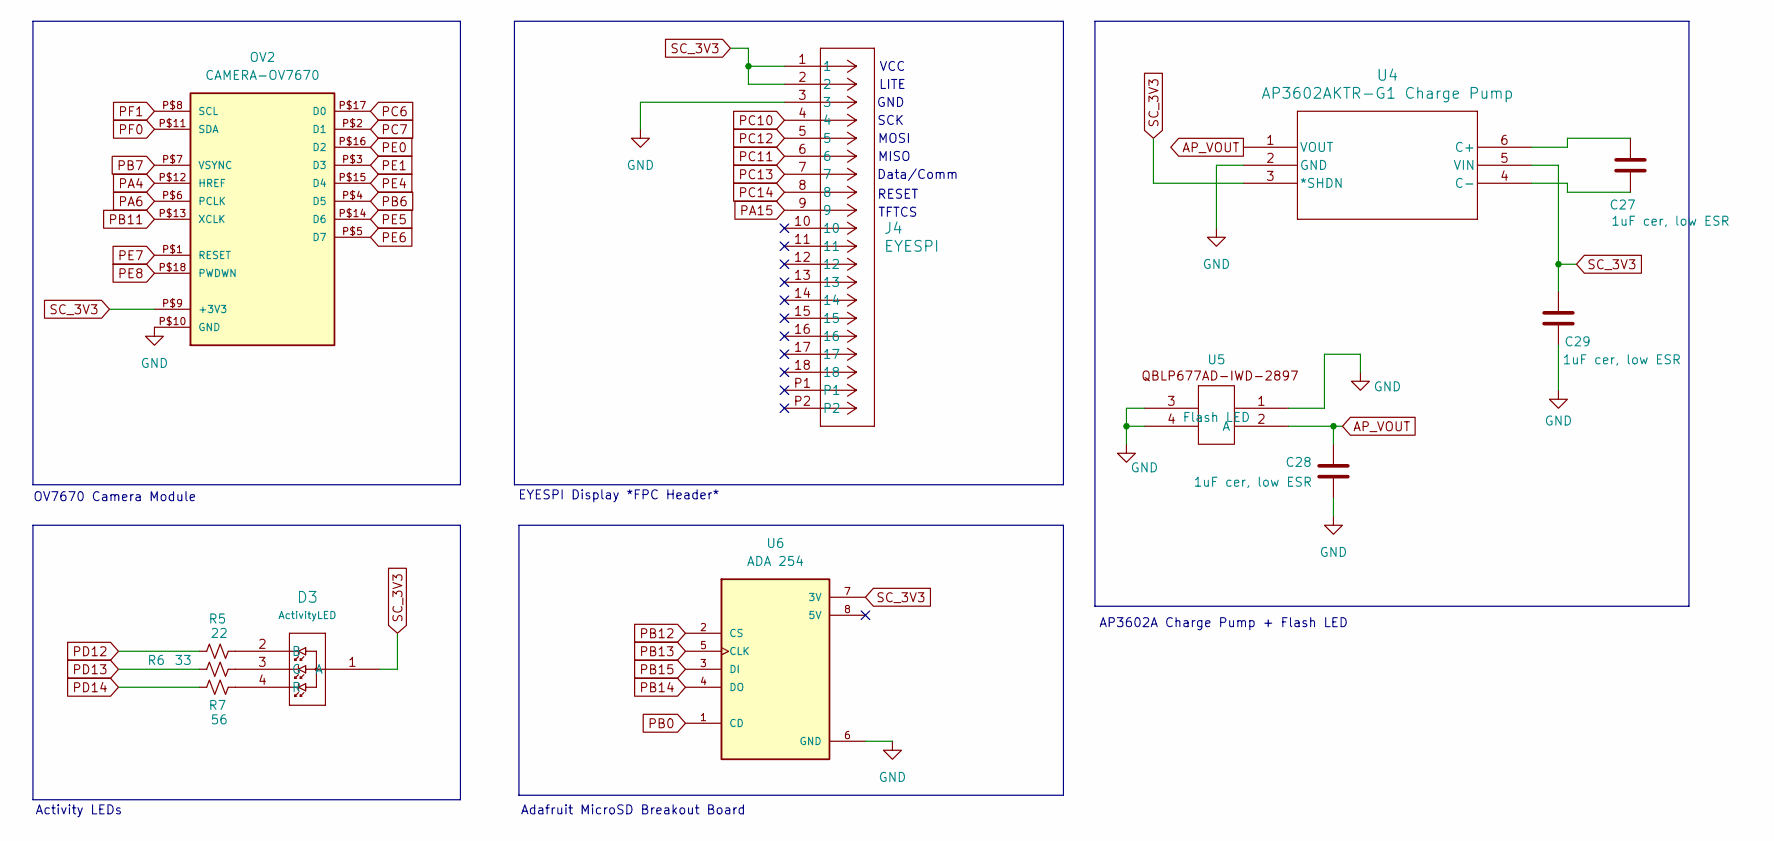
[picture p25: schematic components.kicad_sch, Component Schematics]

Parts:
C27, C28, C29: 1uF cer, low ESR; C_0603_1608Metric
D3: ActivityLED; CLMVC-FKA-CL1D1L71BB7C3C3_CRE
J4: EYESPI; CON_5051101892_MOL
OV2: CAMERA-OV7670; CAMERA-OV7670-DIP
R5: 22; R_0402_1005Metric
R6: 33; R_0402_1005Metric
R7: 56; R_0402_1005Metric
U4: AP3602AKTR-G1 Charge Pump; SOT-23-6_DIO
U5: Flash LED; QBLP677AD-IWD-2897
U6: ADA 254; MODULE_254; PARTREV Jul 31, 2013

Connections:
AP_VOUT: C28.1, U4.1 (VOUT), U5.2 (A_2)
BATT-: C28.2, C29.2, J4.3, OV2.P$10 (GND), U4.2 (GND), U5.1, U5.3, U5.4, U6.6 (GND); also elsewhere on the board
unnamed: D3.2 (B), R5.2
unnamed: D3.3 (G), R6.2
unnamed: D3.4 (R), R7.2
unnamed: C27.1, U4.6 (C+)
unnamed: C27.2, U4.4 (C-)
PA4: OV2.P$12 (HREF); also elsewhere on the board
PA6: OV2.P$6 (PCLK); also elsewhere on the board
PA15: J4.9; also elsewhere on the board
PB0: U6.1 (CD); also elsewhere on the board
PB6: OV2.P$4 (D5); also elsewhere on the board
PB7: OV2.P$7 (VSYNC); also elsewhere on the board
PB11: OV2.P$13 (XCLK); also elsewhere on the board
PB12: U6.2 (CS); also elsewhere on the board
PB13: U6.5 (CLK); also elsewhere on the board
PB14: U6.4 (DO); also elsewhere on the board
PB15: U6.3 (DI); also elsewhere on the board
PC6: OV2.P$17 (D0); also elsewhere on the board
PC7: OV2.P$2 (D1); also elsewhere on the board
PC10: J4.4; also elsewhere on the board
PC11: J4.6; also elsewhere on the board
PC12: J4.5; also elsewhere on the board
PC13: J4.7; also elsewhere on the board
PC14: J4.8; also elsewhere on the board
PD12: R5.1; also elsewhere on the board
PD13: R6.1; also elsewhere on the board
PD14: R7.1; also elsewhere on the board
PE0: OV2.P$16 (D2); also elsewhere on the board
PE1: OV2.P$3 (D3); also elsewhere on the board
PE4: OV2.P$15 (D4); also elsewhere on the board
PE5: OV2.P$14 (D6); also elsewhere on the board
PE6: OV2.P$5 (D7); also elsewhere on the board
PE7: OV2.P$1 (RESET); also elsewhere on the board
PE8: OV2.P$18 (PWDWN); also elsewhere on the board
PF0: OV2.P$11 (SDA); also elsewhere on the board
PF1: OV2.P$8 (SCL); also elsewhere on the board
SC_3V3: C29.1, D3.1 (A), J4.1, J4.2, OV2.P$9 (+3V3), U4.3 (*SHDN), U4.5 (VIN), U6.7 (3V); also elsewhere on the board

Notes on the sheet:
AP3602A Charge Pump + Flash LED
EYESPI Display *FPC Header*
MISO
SCK
LITE
RESET
MOSI
Data/Comm
Adafruit MicroSD Breakout Board
VCC
Activity LEDs
TFTCS
GND
OV7670 Camera Module

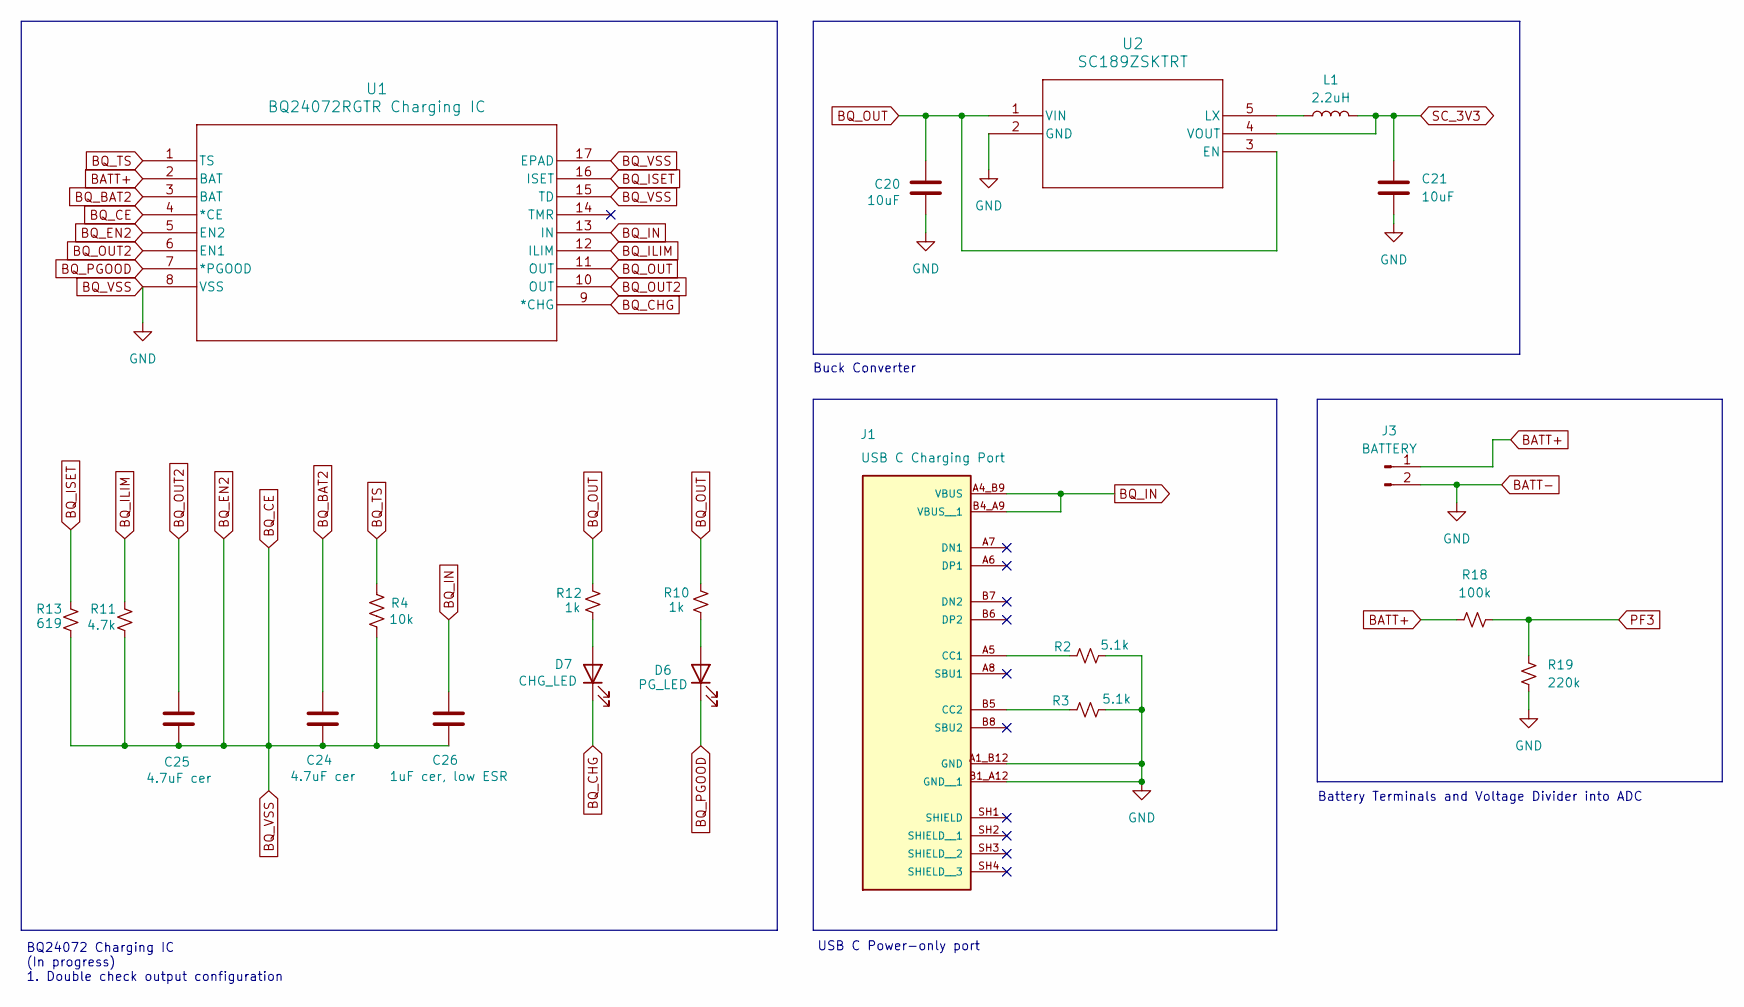
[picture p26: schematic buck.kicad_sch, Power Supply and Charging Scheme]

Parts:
C20, C21: 10uF; C_0603_1608Metric
C24, C25: 4.7uF cer; C_0805_2012Metric
C26: 1uF cer, low ESR; C_0603_1608Metric
D6: PG_LED; LEDM1608X80_G
D7: CHG_LED; LEDC1608X35N_R
J1: USB C Charging Port; SAMESKY_UJ20-C-H-G-SMT-1-P16-TR; PARTREV 1.0
J3: BATTERY; JST_B2B-XH-A
L1: 2.2uH; L_1008_2520Metric
R2, R3: 5.1k; R_0402_1005Metric
R4: 10k; R_0402_1005Metric
R10, R12: 1k; R_0402_1005Metric
R11: 4.7k; R_0402_1005Metric
R13: 619; R_0402_1005Metric
R18: 100k; R_0402_1005Metric
R19: 220k; R_0805_2012Metric
U1: BQ24072RGTR Charging IC; RGT16_1P7X1P7
U2: SC189ZSKTRT; SOT23-5-SC189_SEM

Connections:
BATT+: J3.1, R18.1, U1.2 (BAT)
BATT-: C20.2, C21.2, C24.2, C25.2, C26.2, J1.A1_B12 (GND), J1.B1_A12 (GND__1), J3.2, R2.2, R3.2, R4.1, R11.2, R13.2, R19.2, U1.4 (*CE), U1.5 (EN2), U1.8 (VSS), U1.15 (TD), U1.17 (EPAD), U1.V, U2.2 (GND); also elsewhere on the board
BQ_BAT2: C24.1, U1.3 (BAT)
BQ_CHG: D7.C (K), U1.9 (*CHG)
BQ_ILIM: R11.1, U1.12 (ILIM)
BQ_IN: C26.1, J1.A4_B9 (VBUS), J1.B4_A9 (VBUS__1), U1.13 (IN)
BQ_ISET: R13.1, U1.16 (ISET)
BQ_OUT: C20.1, R10.1, R12.1, U1.11 (OUT), U2.1 (VIN), U2.3 (EN)
BQ_OUT2: C25.1, U1.6 (EN1), U1.10 (OUT)
BQ_PGOOD: D6.C (K), U1.7 (*PGOOD)
BQ_TS: R4.2, U1.1 (TS)
unnamed: D6.A, R10.2
unnamed: D7.A, R12.2
unnamed: J1.A5 (CC1), R2.1
unnamed: J1.B5 (CC2), R3.1
unnamed: L1.1, U2.5 (LX)
PF3: R18.2, R19.1; also elsewhere on the board
SC_3V3: C21.1, L1.2, U2.4 (VOUT); also elsewhere on the board

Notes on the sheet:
Battery Terminals and Voltage Divider into ADC
BQ24072 Charging IC (In progress) 1. Double check output configuration
Buck Converter
USB C Power-only port

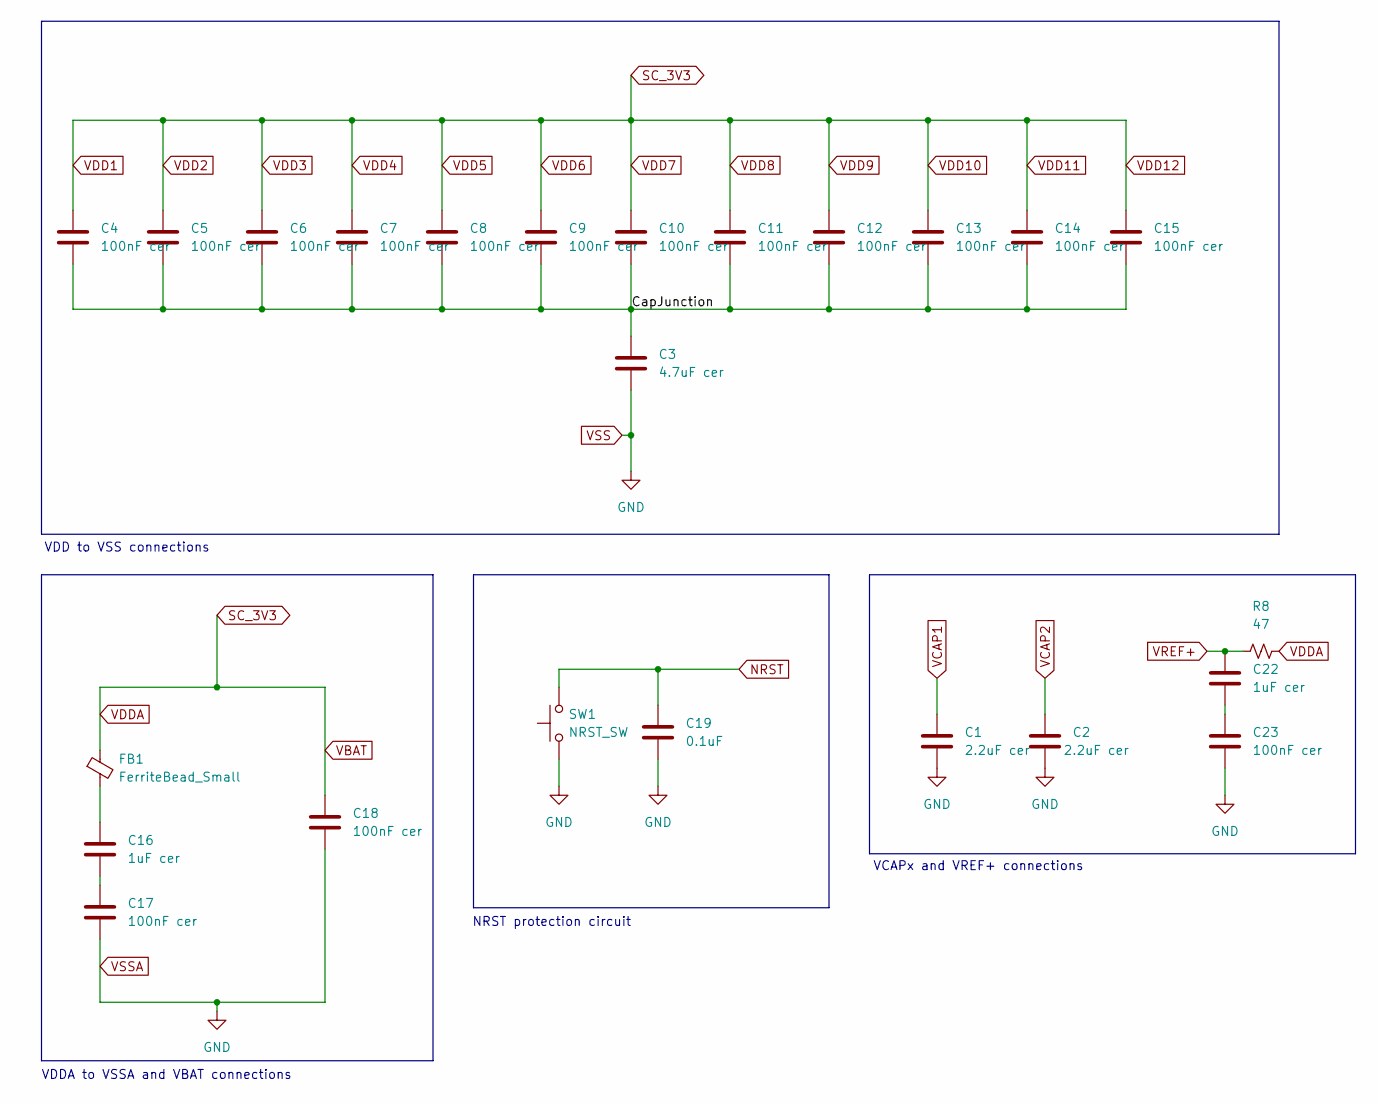
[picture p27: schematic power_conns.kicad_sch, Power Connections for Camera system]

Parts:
C1, C2: 2.2uF cer; C_0201_0603Metric
C3: 4.7uF cer; C_0805_2012Metric
C4, C5, C6, C7, C8, C9, C10, C11, C12, C13, C14, C15, C17, C18, C23: 100nF cer; C_0603_1608Metric
C16, C22: 1uF cer; C_0603_1608Metric
C19: 0.1uF; C_0603_1608Metric
FB1: FerriteBead_Small; BEADC1608X95N
R8: 47; R_1206_3216Metric
SW1: NRST_SW; SW_SKRPABE010

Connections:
/STM32_Power_Requirements/CapJunction: C3.1, C4.2, C5.2, C6.2, C7.2, C8.2, C9.2, C10.2, C11.2, C12.2, C13.2, C14.2, C15.2
BATT-: C1.2, C2.2, C3.2, C17.2, C18.2, C19.2, C23.2, SW1.1; also elsewhere on the board
NRST: C19.1, SW1.2; also elsewhere on the board
unnamed: C16.1, FB1.2
unnamed: C16.2, C17.1
unnamed: C22.2, C23.1
SC_3V3: C4.1, C5.1, C6.1, C7.1, C8.1, C9.1, C10.1, C11.1, C12.1, C13.1, C14.1, C15.1, C18.1, FB1.1, R8.2; also elsewhere on the board
VCAP1: C1.1; also elsewhere on the board
VCAP2: C2.1; also elsewhere on the board
VREF+: C22.1, R8.1; also elsewhere on the board

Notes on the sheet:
VDDA to VSSA and VBAT connections
VCAPx and VREF+ connections
NRST protection circuit
VDD to VSS connections

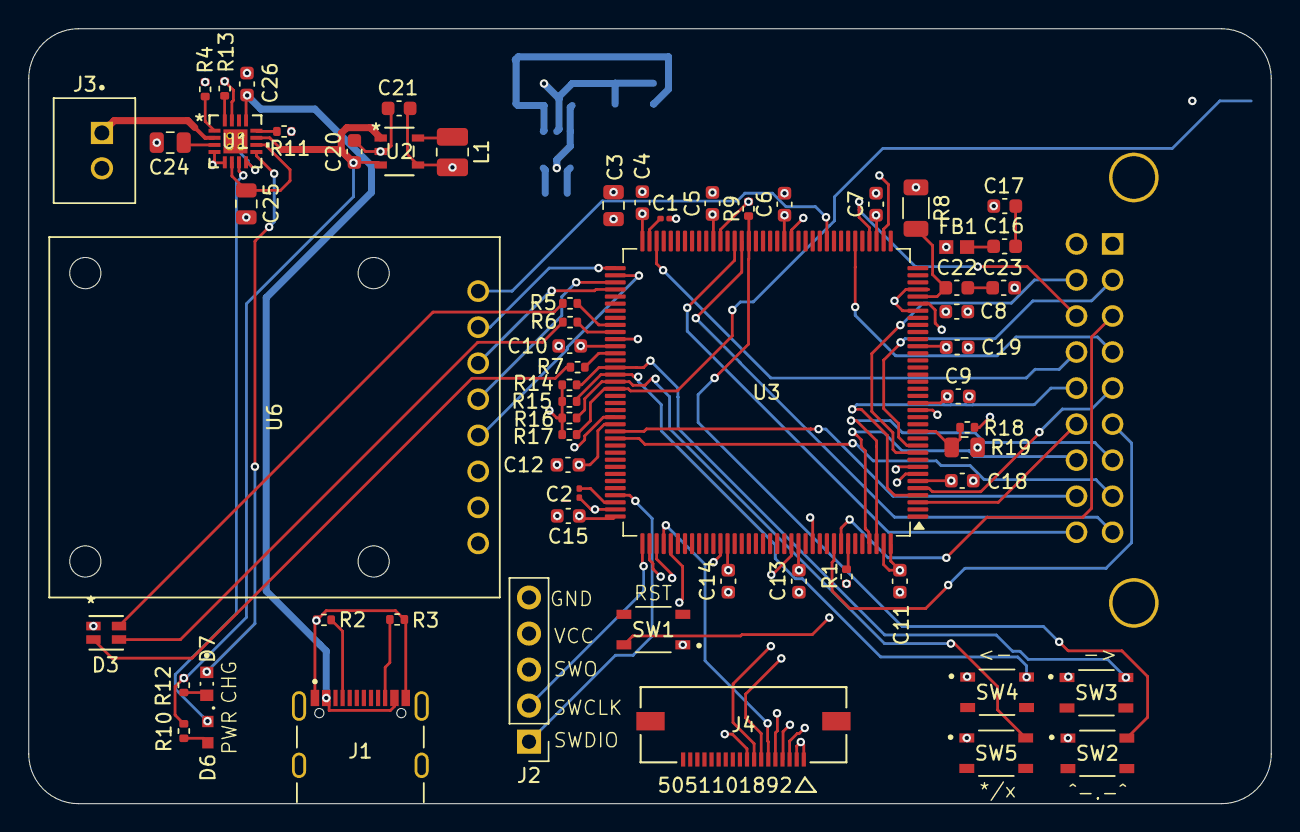
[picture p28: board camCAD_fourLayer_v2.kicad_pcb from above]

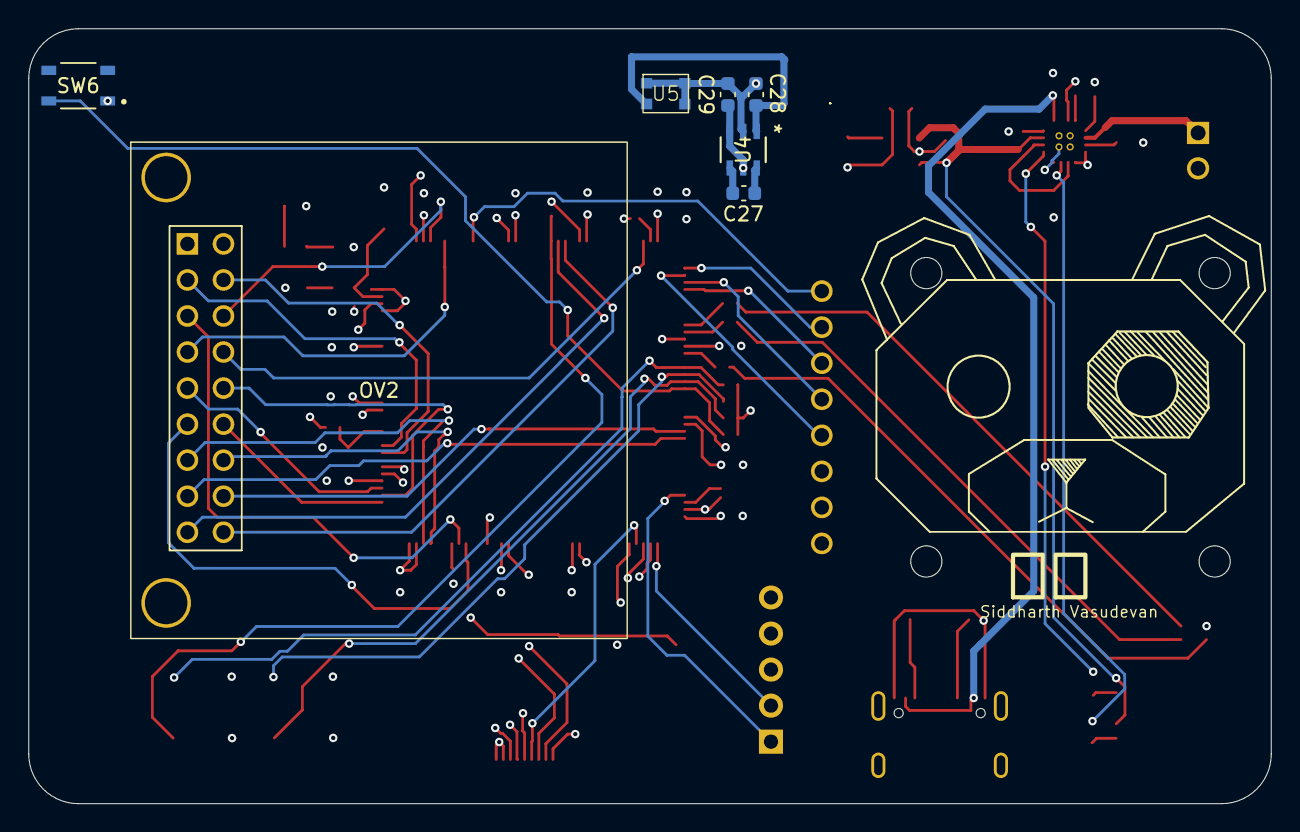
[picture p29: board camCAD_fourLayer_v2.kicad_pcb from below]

Board: 4 copper layers, 87.6 x 54.6 mm, 70 parts (7 on the bottom side), 71 nets.

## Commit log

2026-05-29 First push
    [camCAD.kicad_pcb, camCAD.kicad_sch]
2026-05-31 Debug + MicroSD connections complete
    [camCAD.kicad_sch]
2026-06-02 Finished connections for ILI9341, power incomplete
    [camCAD.kicad_sch]
2026-06-05 Push before adding power configuration
    [camCAD.kicad_sch]
2026-06-05 working on power
    [camCAD.kicad_sch, peripherals.kicad_sch]
2026-06-05 restarted power
    [camCAD.kicad_sch, pers.kicad_sch, power_conns.kicad_sch]
2026-06-05 removing previous sheet, buggy
    [peripherals.kicad_sch]
2026-06-09 Included buck converter schematic
    [buck.kicad_sch, camCAD.kicad_sch, pers.kicad_sch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]
2026-06-09 restructured hierarchy and cleaned up schematic
    [buck.kicad_sch, camCAD.kicad_sch, components.kicad_sch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]
2026-06-11 Added battery to HardwareNotes.md, some touch ups on schematic
    [buck.kicad_sch, camCAD.kicad_sch, components.kicad_sch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]
2026-06-13 Adding charging functionality
    [buck.kicad_sch, camCAD.kicad_sch, components.kicad_sch]
2026-07-01 Nearly done with DPPM connections, updated readme
    [buck.kicad_sch, components.kicad_sch, power_conns.kicad_sch]
2026-07-01 Completed charging schematic, updated readme
    [buck.kicad_sch]
2026-07-09 miscellaneous changes
    [buck.kicad_sch, components.kicad_sch, f407zgt6.kicad_sch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]
2026-07-25 Added footprints for major components, renamed some components for more specific information
    [buck.kicad_sch, camCAD.kicad_sch, components.kicad_sch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]
2026-07-26 Started PCB Layout, need to add a user interface
    [camCAD.kicad_pcb, camCAD.kicad_sch, components.kicad_sch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]
2026-08-06 Added user interface schematic and updated "camCAD/README.md"
    [buck.kicad_sch, f407zgt6.kicad_sch, user_interface.kicad_sch]
2026-08-06 Rearranged layout
    [camCAD.kicad_pcb, power_conns.kicad_sch]
2026-08-14 Random push ishan karne
    [buck.kicad_sch, camCAD.kicad_pcb, power_conns.kicad_sch]
2026-08-28 layout partially complete
    [buck.kicad_sch, camCAD.kicad_pcb, power_conns.kicad_sch]
2026-09-18 Modified pcb layout
    [camCAD.kicad_pcb]
2026-09-18 Completed two layer PCB first draft
    [camCAD_twoLayer.kicad_pcb]
2026-09-18 Updated Schematic README
    [camCAD_fourLayer.kicad_pcb]
2026-09-19 Starting 4 layer layout
    [camCAD_fourLayer.kicad_pcb]
2026-09-19 Made some progress on four layers
    [camCAD_fourLayer.kicad_pcb]
2026-09-19 Completed first draft of four layer, updated layout readme
    [camCAD_fourLayer.kicad_pcb]
2026-09-20 Modified power trace widths and updated Readme
    [camCAD_fourLayer.kicad_pcb]
2026-09-20 REMADE with a much more suitable display
    [buck.kicad_sch, camCAD_fourLayer_v2.kicad_pcb, camCAD_fourLayer_v2.kicad_sch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]
2026-09-22 Push post-print
    [camCAD.kicad_sch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]
2026-09-22 Post print push
    [camCAD_fourLayer_v2-B_Cu.gbr, camCAD_fourLayer_v2-B_Mask.gbr, camCAD_fourLayer_v2-B_Paste.gbr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]
